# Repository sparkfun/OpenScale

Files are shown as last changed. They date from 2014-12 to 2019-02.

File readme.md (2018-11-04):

SparkFun OpenScale
===========================================================

SparkFun OpenScale (https://www.sparkfun.com/products/13261)

[*SparkFun OpenScale (SEN-13261)*](https://www.sparkfun.com/products/13261)

The SparkFun OpenScale is a simple-to-use, open source solution for measuring weight and temperature. It has the ability to read multiple types of load cells and offers a simple-to-use serial menu to configure calibration value, sample rate, time stamp and units of precision.

Simply attach a four-wire or five-wire load cell of any capacity, plug the OpenScale into a USB port, open a terminal window at 9,600bps, and you’ll immediately see mass readings. The SparkFun OpenScale will enable you to turn a load cell or four load sensors in a Wheatstone bridge configuration into the DIY weigh scale for your application.

The OpenScale was designed for projects and applications where the load was static (like the beehive in front of SparkFun HQ) or where constant readings are needed without user intervention (for example, on a conveyor belt system). A load cell with an equipped OpenScale can remain in place for months without needing user interaction!

On board the SparkFun OpenScale is the ATmega328P microcontroller, for addressing your communications needs and transferring your data to a serial terminal or to a data logger such as the OpenLog, an FT231 with mini USB, for USB to serial connection; the HX711, a 24-bit ADC for weigh scales; and the TMP102, for recording the ambient temperature of your system. The OpenScale communicates at a TTL level of 9,600bps 8-N-1 by default and possesses a baud rate configurable from 1,200bps to 1,000,000bps.

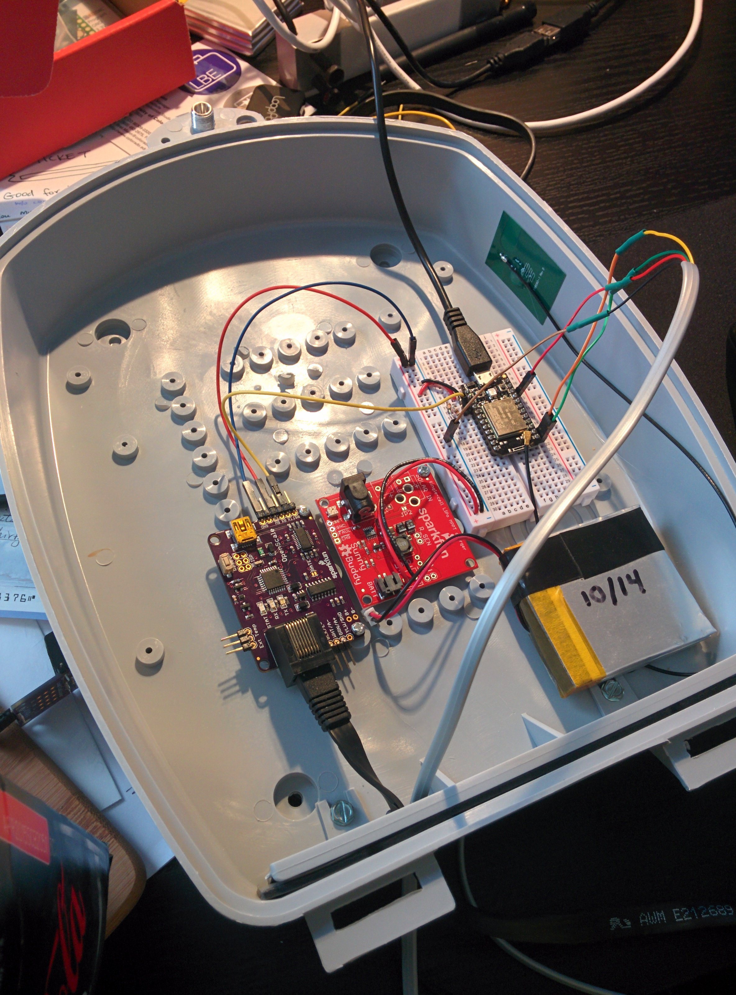
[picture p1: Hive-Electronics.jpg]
The electronics monitoring the bee hive


You can read more about the beehive project that OpenScale is used in the [Internet of Bees](http://makezine.com/projects/bees-sensors-monitor-hive-health/) article.

Repository Contents
-------------------

* **/Documentation** - Images used in the hookup guide
* **/Production** - PCB panelized for production
* **/firmware** - Arduino sketch that runs on the ATmega328P
* **/hardware** - Eagle files

Documentation
--------------

* **[Installing an Arduino Library Guide](https://learn.sparkfun.com/tutorials/installing-an-arduino-library)** - Basic information on how to install an Arduino library.
* **[Hookup Guide](https://learn.sparkfun.com/tutorials/openscale-applications-and-hookup-guide)** - Basic hookup guide for the SparkFun OpenScale

License Information
-------------------

This product is _**open source**_! 

Various bits of the code have different licenses applied. Anything SparkFun wrote is beerware; if you see me (or any other SparkFun employee) at the local, and you've found our code helpful, please buy us a round!

Please use, reuse, and modify these files as you see fit. Please maintain attribution to SparkFun Electronics and release anything derivative under the same license.

Distributed as-is; no warranty is given.

- Your friends at SparkFun.

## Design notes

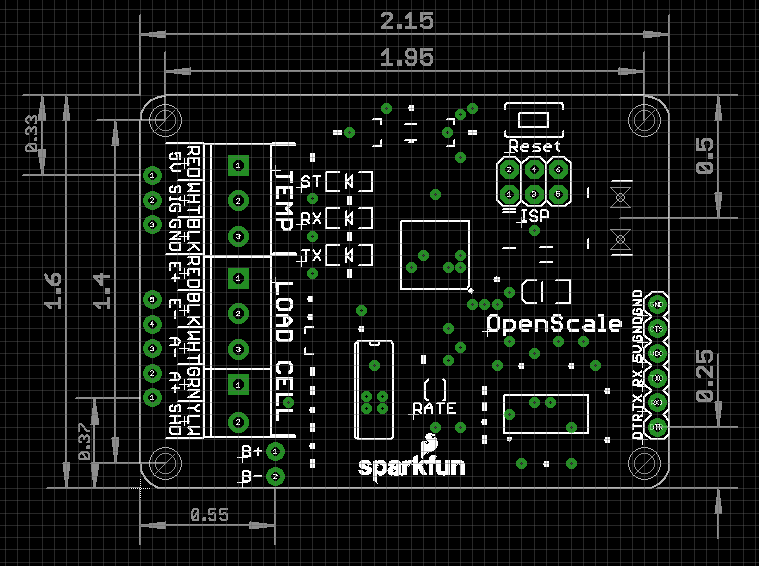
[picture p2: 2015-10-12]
OpenScale Board Dimensions.png

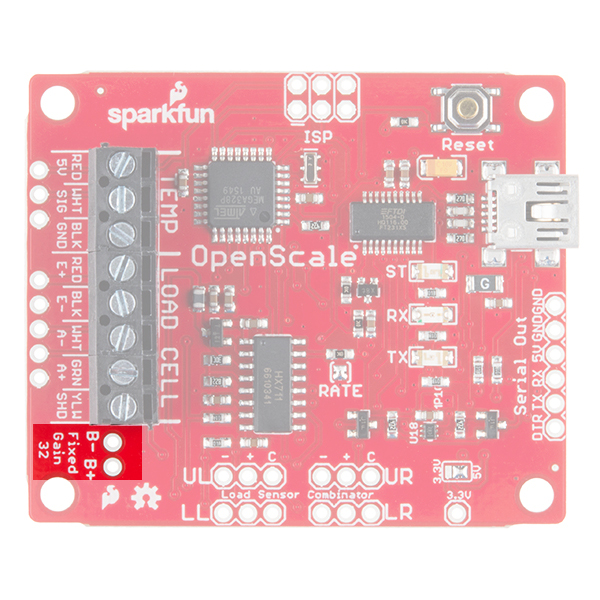
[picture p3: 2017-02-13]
Documentation/OpenScale_gain.jpg

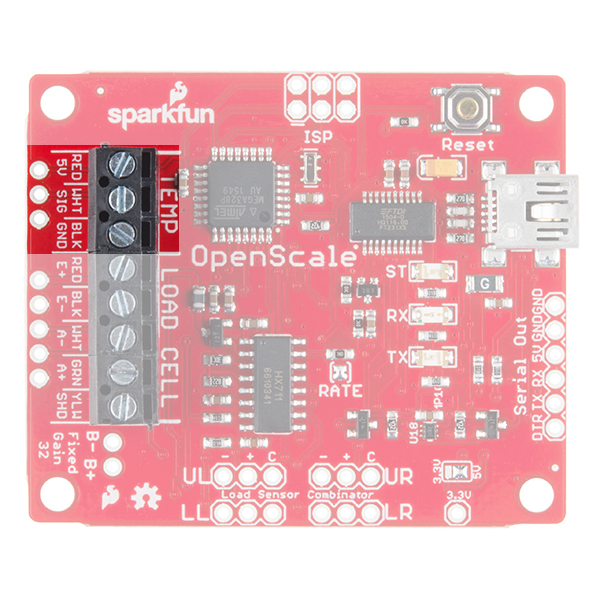
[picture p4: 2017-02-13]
Documentation/OpenScale_TEMP.jpg

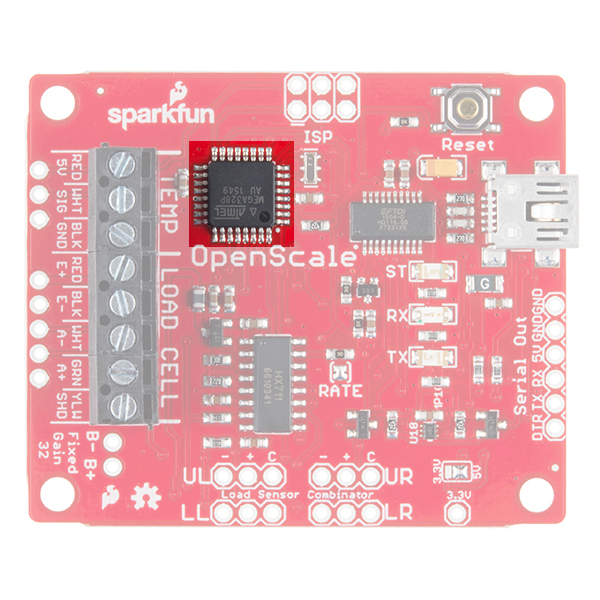
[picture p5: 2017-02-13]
Documentation/OpenScale_atmega.jpg

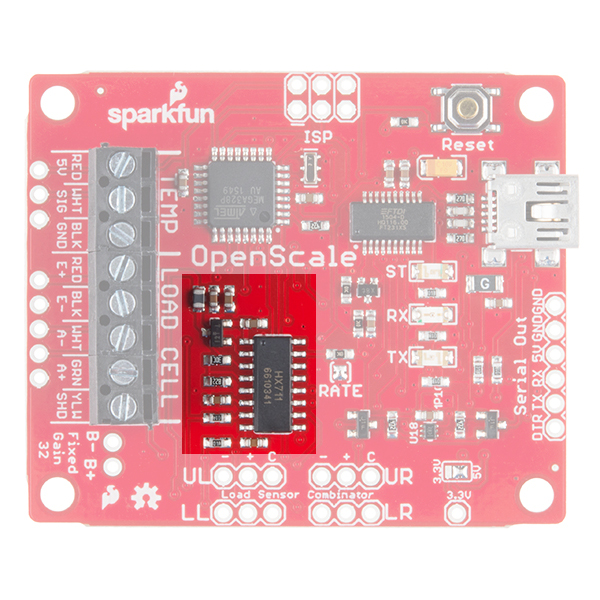
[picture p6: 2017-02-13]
Documentation/OpenScale_HX711.jpg

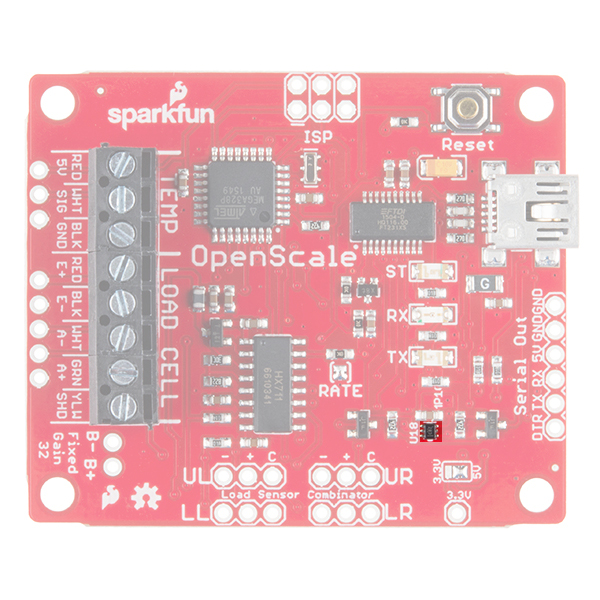
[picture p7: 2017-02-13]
Documentation/OpenScale_Temptiny.jpg

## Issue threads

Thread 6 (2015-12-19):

Commercial product?

zoltan-fedor, 2015-12-19:
Hi,
I know that the readme says that this project is in prototyping phase, but is it expected at any time that this board becomes commercially available, for example via Sparkfun?

Thanks

ToniCorinne, 2015-12-21:
I believe @nseidle is still planning on taking the prototypes and putting them through to Production, but I'm not 100% sure on that timeline.

zoltan-fedor, 2015-12-22:
Thanks @ToniCorinne !

@nseidle , are you still planning on taking this prototype through production? If yes, do you happen to have any timelines?
Thanks

nseidle, 2015-12-22:
Yep! We have protos but there's many steps left. I'm not sure of the timeline but I will guestimate 3-4 months.

@zoltan-fedor - Your interest level helps move the project along. Would you buy the board if it was available? What are you planning on using it for?

zoltan-fedor, 2015-12-22:
Yes, depending on the price I would buy at least one (potentially many more - I might have additional projects around the same topic). My current interest is rebuilding a bee hive scale with OpenScale board. Last year I did it by building a board myself, but would be easier to use a pre-built board.

ToniCorinne, 2016-03-07:
We are working on getting this on the storefront! Closing out the issue, but keep an eye out for the product on the Friday New Product Post.

jgpender, 2016-04-28:
Can I ask about the status of the OpenScale load sensor board? I am also working on a beehive scale that uploads data to phant, hopefully powered for 2-3 months with a couple AA batteries (C cells are plan B). I've bought all the components from Sparkfun - four SEN-10245 load cells, load sensor combinator BOB-13281, HX711 load cell amp, ESP8266 Dev Thing, and a 3.3 step up breakout NCP1402 to keep the supply voltage very constant. Everything works but I am getting huge temperature drift. A temperature change of a few degrees produces a change in the weight reading equivalent to about 10-20 pounds. Realistic temperature swing of 30 degrees are a nightmare. I added a one-wire temperature sensor to the 8266 in the hopes that I could compensate for the drift in software but I can't get the noise level down to the +/- 1 pound I'd hoped for. Does anyone know if the OpenScale breakout will help with the temperature problem? I don't need to deploy my scale until about June so I still have time to work on this before it's too late for this season. Thanks very much, John.

zoltan-fedor, 2016-04-28:
I have just finished building mine, but I didn't use the OpenScale board, but built mine.
I believe the big difference that I did not build the scale, but using one already built : http://www.amazon.com/TREE-Measurements-Large-Shipping-Scale/dp/B008M8FND6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
Expensive, but reliable, no creep. Left some wait on it for 3 weeks and there wasn't even a 0.1 lb creep.

Also I am using a Particle Electron, so it communicates via the 2G network. Plus it has two batteries, a Lipo and a normal USB battery bank and it charges itself from the UBS battery bank whenever needed, so you can swap the battery bank out whenever you want.

jgpender, 2016-04-28:
Hiya Zoltan-

How does that work? Do you strip off the display and then tap into the weight reading somehow? I’m assuming this scale works so well either because it uses better load sensors than the Sparkfun set or because it’s somehow built in the temperature compensation. What sort of temperature swing do you get?

Part of what motivated my project was keeping the cost low. I have friends around here with 50-60 hives so $80 just for the scale would break the budget into a million pieces.

Thanks very much,
John

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

zoltan-fedor, 2016-04-28:
Hi John,
Yes, this is my second generation bee-scale, last year I built one too - that was with a low-end scale and I had all kind of problems with the reliability of the scale (although no major temperature swings). Currently I am not seeing any temperature swings and this is a high-end scale, so I would be surprised to see any.
Yes, I just stripped off the display and connected the HX711 load cell amp and did the calibration and that's it. I was testing the whole setup in the last 2 weeks - working pretty well.
I really like the Electron, although I must say there were quite a few gotchas when I had to bug the guys at Particle to find solutions to problems of the Electron, specially around sleep modes, low power stages, keeping 2G connection alive, etc.

Zoltan

ps.: Yes, $80 is pretty expensive, but me being a beekeper myself - I would never put a scale under each hive, no point in that, at least not for what I use it. I usually put a scale under a single hive or maybe two - as it is used as an indicator of nectar flow, not the health of the individual hive, so that way it worth the investment for a whole yard.
But yes, for generation 3 of my scale, I will probably do some research to find a cheaper version of the scale - one which is still good enough (no creep, no temperature swings, measures up to 200lb, etc), but cheaper

jgpender, 2016-04-28:
Hi Zoltan-

I only have the one hive so the expense of the scale is not a big deal, especially when compared to all the aggravation I’ve had. I tried using the Particle Photon but it froze up a couple times so I thought I’d try the ESP8266 board, partly because of the lower price. Talk about “gotchas.” What a pain that board was. I went ahead and used GND, pin 5, pin 0, and pin 4 to connect to the load cell amp and wasted all kinds of time trying to figure out why it didn’t work. Finally realized you’re supposed to connect pin 0 to ground when you want to reset the bootloader so pin 0 doesn’t sleep when you sleep the board.

Shot myself in the foot a second time when I hooked the one-wire temperature sensor to pins 12 and 16. Sleep mode requires a jumper on the blue oval below and I forgot that XPD was the same as pin 16 so, again, the board wouldn’t sleep.

Personally, I’m most comfortable with the Arduino Yun board because I’ve been using command line Unix for 35 years. Scripting, scp, blah blah blah like falling off a log. Spendy board, though, and no sleep mode.

None of my friends would put a scale under every hive either. Usually they set up maybe a half dozen in some field, then another batch in some other location, etc., so they’d only want a scale under one hive per set. Even so, I heard a lot of whining last fall when we talked about the price, even in the $30 range. It was smart of you to start with an industrial-grade solution then work down to something cheap. Starting cheap has cost me all kinds of time.

John

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

zoltan-fedor, 2016-04-28:
Hi John,
I am doing a lot of linux too for a few years now, so last year I actually built the whole thing on a Raspberry, but I had a challenge managing its power needs, so now I went for the Particle Electron. I am operating it in the middle of the woods (literally, we take the hives to a black lotus forest), where there is no power source, wifi or anything else (but the woods). :-)

For now I am pretty happy with the Particle Electron. I can run it for about 4-5 days from the included 2000mAh battery making a measurement and sending it to my server in every 15 mins and I can add an any-size external USB power bank and it charges itself from it when the 2000mAh runs low (using a relay switching the USB cabel, because power banks turn themselves off after low power use - when the 2000mAh is full).
I can get a 10000mAh USB power bank fairly cheap ($10), so with that the setup can run for about 24 days in total.
Going any higher would require adding a solar panel (which I did for some other projects) or decreasing measuring frequency to save power.

All-in-all, I am happy with the choice of going industrial-grade with the scale for now and then working down when (if) I plan to produce multiple of these scales.
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
ADataDate, 2016-04-29:
You might also want to look into noise that might be on your lines. Another
cool thing about openscale is that Nate added an inductor on the digital
input so some of that noise is immediately filtered. The Inoor weight
actually looks pretty good compared to the outdoor but I can see why would
be frustrated if you are trying to the readings into +/- 1% tolerance.

I would order new load cells. The problem with buying a scale is that you
will get load sensors instead of cells and you would have to configure them
into a whetstone bridge to get it working properly. Do you know the max
weight of what you are trying weigh? We have this Load Cell (data sheet
below as well). It has a pretty good temperature range, creep is +/-0.03%
every 3 minutes.
https://www.sparkfun.com/products/13329
https://cdn.sparkfun.com/datasheets/Sensors/ForceFlex/TAL220M4M5Update.pdf

There are certainly better load cells out there for different applications.
I would check out Honeywell, I usually stop there first for more robust
mechanical projects.

To start compensating the system I would look at one varying factor at a
time. This is how I would get my comp coefficients:
For Creep:
Take a known weight and put in on the scale for as long as the data sheet
says before it needs to tare (in the load cell above its every 3 minutes).
Measure the difference in the measured weight against the known weight. Do
this several times and increase the amount of time with each test.
Eventually you should get a curve which you could probably linearize if you
wanted to keep things a little more simple. The slope of the linear curve
would be your creep coefficient. Yo'll probably need to update this value
often as the creep will change with time.

For Temp:
Do basically the same thing in as much of a controlled environment as you
can. Get ambient readings first then take it outside to get the crazy
stuff. when taking it outside try to shield your setup from as much other
environmental forces as possible. It would be great to characterize the
curve based on you controlling the temperature & humidity/pressure, Since
that isn't totally possible this curve fitting may take some time. Once I
have a coefficient I can test I would set a known weight on the scale in
known temps with an idea of the error might be and adjust the coefficient
statically. You may need to update this value often.

For environmental factors:
Can you dig posts down into the ground, basically create a foundation for
your setup? then it is more likely your setup will not be as susceptible to
vibration. Can you create a housing around the electronics and the
object(s) you are weighing? This will help with wind forces. Though it
would be interesting to see a map of readings with weather data laid over
to see possible correlations. I'd use nice and thick cables, plenty of
electrical tape. Moisture is bad news for transmission.

I'd like to see your data again when you have it set up with OpenScale and
new load cells.

Send me an email at mary.west@sparkfun.com and I'll get you a prototype
loaded the the first sketch ready to go by this afternoon.

Thanks for sharing your progress!

On Thu, Apr 28, 2016 at 4:58 PM, John Pender <notifications@github.com>
wrote:

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

abohnsac, 2016-09-06:
I'm new to all of this but wondering if anyone has any new information on using the openscale board with their hive sensors. It seems like this should make it more simple and that this has progressed since the release of the board. I'm planning on using it with the raspberry pi 3 to broadcast data. Any guidance or advice is appreciated.

Closed 2016-03-07.

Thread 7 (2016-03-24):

v04 Checklist issues

ericorosel, 2016-03-24:
1) May want to add your name to the Engineer field, currently it's just Nate's (not sure who's board it is)

2) SCH and BRD both show v03, I think it should say v04

3) There is a 470pF CAP on the BOM (CAP-07884) that I couldn't find in the design

4) Need to run the DRC with a vetted DRC from GitHub in the Sparkfun_eagle_settings repo (currently set to Sparkfun_2-Layer which is old)

5) 27 ohm resistors do not have silk in the package

6) looks like the inductor needs a prod id in the attributes

I think that's it!

ericorosel, 2016-03-24:
Just realized I did a check on the wrong design, my bad.

Closed 2016-03-24.

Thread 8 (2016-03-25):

Actual v04 Checklist Review

ericorosel, 2016-03-25:
1) some nets are not drawn straight out one grid space from the pin: J2, R12, R11

2) got some over sized nets around the FT chip (> 0.006")

3) I would like to see a jumper diagram for the 3-way jumper, otherwise I think the description needs some cleaning up

4) BOM:
- 470pf on BOM not in design
- 4 x 10K in design but only 2 on BOM
- Push Button in design and on BOM are different
- TRANS-11151 not on BOM

5) board dimension thickness is 0.1" instead of 0.08"

6) there are both 0.02" vias and 0.015" vias in the design (didn't look intentional)

7) C4 has an unnecessary bridge to GND (just looks kind of funny)

8) the trace-nubs at the end of the pads on the USB look like they were intentionally placed there, is this for AOI inspection?

9) This is knit-picky, but there are a few traces that either enter a pad at an angle or do not enter the pad at the pad's center point. Some of the mentioned instances are in tightly spaced areas, but some are not. Might be worth trying to clean up some of the instances that have some extra space around them. (optional)

10) TMP102 does not appear to have tNAME or tVALUE elements in the BRD

11) Looks like the bottom-side labels for JP1 (the 3 x 1 Temp header) are no longer lined up with the through-holes

12) Not sure if the upper two standoffs were intentionally placed out from the corner of the board, but I thought it worth mentioning if this was unintentional.

ADataDate, 2016-03-29:
Board and Schematic files updated.

ericorosel, 2016-03-29:
Issues all resolved, closing!

Closed 2016-03-29.

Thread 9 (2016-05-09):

Engineering Review

ToniCorinne, 2016-05-09:
- Move "All units in inches" note to Measures layer
- scoot passives out from USB connector(20 mils) for AOI
- bump miter out 1 0.5 grid space
- move mounting hole on grid
- Update schematic text to vector

- Following on hold until verifying with Nate:
- Change silk to  "FTDI Out" / "Serial Out"
- Update FTDI silk to RXI, TXO

ToniCorinne, 2016-07-15:
Closing this out

Closed 2016-07-15.

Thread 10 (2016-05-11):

Engineering checklist issues:

ericorosel, 2016-05-11:
(1) The design version number is still v04 - This should be v10 if we go to REDS or v05 id we do another proto round. Ether way, the version number needs to change in order to reflect changes from v04.

(2) Need an extra CAP-00810 in the BOM. Currently the design has 9 0.1uf caps and the BOM only reflects 8 of the 9.

(3) I think if the "Serial Ou"t header is to be used as a general serial out, then we should adjust the header so that another micro (pro mini, oplelog, etc.) could be connected directly to the OpenScale with female and male headers without the use of jumper wires. Right now the header is set to mate with an FTDI, which is all good, but it seems redundant given the board has an on-board FTDI chip and a USB connector. I think it would be more intuitive to order the pins similarly to the FTDI's for easy connection to another micro based device. If I am completely off base as to the function of this header please disregard the above.

(4) I know that C14 is directly in the way of the "Serial Out" label being centered, but it would be nice to have that label centered on the header. Maybe smaller font could make this doable. If the font size is already at it's minimum for the need of the design then disregard.

(5) Looks like the trace connecting to the TMP on pin 3 is entering the pad at an angle. It would be nice to have that trace enter the pad at the toe like the rest.

(6) Top copper polygon gets chopped at the corners of the board. I think it would be nice to mimic the bottom copper polygon in nature (same dimension border).

ericorosel, 2016-05-11:
Mary just reminded me that the Openlog has the same serial header arrangement as the FTDI, which makes point (3) not an issue at all. Please disregard point (3), and my apologies for the confusion.

ADataDate, 2016-05-11:
Hey Eric,

Pushing changes now. Sorry if this has been frustrating for you. Glad I
have my revision quota done for the year.

(1) The design version number is still v04 - This should be v10 if we go to
REDS or v05 id we do another proto round. Ether way, the version number
needs to change in order to reflect changes from v04. - Changed to v10. The
only changes are adding a cap, connecting the FET to 3.3V which is how it
should be (and when i cut traces and added jumper to exposed trace it
worked perfectly), rounded corners, silk. I don't see how these changes
would affect the performance or intended use of this product. I'd rather
get a product out. However, if you feel it should go for another round of
protos I will take that into consideration as you have more experience with
these types of things here at Sparkfun.

(2) Need an extra CAP-00810 in the BOM. Currently the design has 9 0.1uf
caps and the BOM only reflects 8 of the 9. - Added part in Sparkle

(3) I think if the "Serial Ou"t header is to be used as a general serial
out, then we should adjust the header so that another micro (pro mini,
oplelog, etc.) could be connected directly to the OpenScale with female and
male headers without the use of jumper wires. Right now the header is set
to mate with an FTDI, which is all good, but it seems redundant given the
board has an on-board FTDI chip and a USB connector. I think it would be
more intuitive to order the pins similarly to the FTDI's for easy
connection to another micro based device. If I am completely off base as to
the function of this header please disregard the above. - Discussed, we
agree to keep it the way it is

(4) I know that C14 is directly in the way of the "Serial Out" label being
centered, but it would be nice to have that label centered on the header.
Maybe smaller font could make this doable. If the font size is already at
it's minimum for the need of the design then disregard. - Changed size &
Centered.

(5) Looks like the trace connecting to the TMP on pin 3 is entering the pad
at an angle. It would be nice to have that trace enter the pad at the toe
like the rest. - Done, good catch

(6) Top copper polygon gets chopped at the corners of the board. I think it
would be nice to mimic the bottom copper polygon in nature (same dimension
border). - Done

Mary

On Wed, May 11, 2016 at 2:05 PM, ericorosel <notifications@github.com>
wrote:

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

ADataDate, 2016-05-11:
https://github.com/sparkfun/OpenScale/tree/v04

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

Closed 2016-05-11.

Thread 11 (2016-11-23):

Screw Terminals in .brd/.sch Files

elizabethsrobert, 2016-11-23:
Hello OpenScale!

The Assembly BOM and storefront pictures show two 3-Screw Terminals and one 2-Screw Terminal being used to populate the board. The .Brd/.Sch Files do not reflect this production change. To complete the 3D model image properly, I just need the number/type of screw terminals changed to reflect this as well as their values. Currently, files have one 3-Screw Terminal and one 5-Screw Terminal.

Thank you!

elizabethsrobert, 2016-12-02:
Used original intended parts to complete 3D design model.

Closed 2016-12-02.

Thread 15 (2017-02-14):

[Feature Request] Consistent weight measurements across a range of temperatures

kevinjos, 2017-02-14:
I notice in a days sample of recordings that weight is a function of temperature W(t). Has anyone taken a look at modeling this relationship such that the OpenScale can be configured to output consistent weight measurements across a range of temperatures (0 - 40C)? What is the major contributing factor? Is it the temperature drift of the [ADC](http://image.dfrobot.com/image/data/SEN0160/hx711_english.pdf)? Or a property of the materials used in the strain gauge? If it's the former it might be worth correcting in the OpenScale firmware. The latter may require scale-specific calibrations.

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

ADataDate, 2017-02-14:
In the photos above are you weighing something constant? A 10 degree change in 2 minutes is definitely going to place mechanical stress on the load cell to cause problems.  A one pound change over 10 minutes does seem excessive though.

This is actually common and expensive problem for a couple of reasons. The HX711 load cell amplifier has an input offset of +/- 6nV/C. This offset can drift further with temperature. Another reason is load hysteresis, which is a mechanical property of the load cell itself. Since each load cell has it's own range for the drift- if you are using 4 strain gauges the readings could be much more off. Keeping the temperature stable in your system is the best way to deal with this but it will still drift some. But will be mostly creep if you can get your system to be more temp independent.  creep causes issues with the hysteresis as well. Creep fatigue happens within the first few moments of a weight reading, then there's a "bounce back" or creep recovery effect as the gauge gets used to deformation.

 NIST actually did a study on creep and found there is a great variety in the magnitude, direction and complexity of the creep between 11 identical strain gauges.  To compensate for this I'd recommend placing a known weight on the scale for 10 minutes or so and calculate the change in weight with time. This test will work best if the temperature is stable. Most creep will occur in the first few moments and should taper off. I'd repeat this test with several weights since you can't assume the creep in constant between different sets of known weights.

https://www.nist.gov/sites/default/files/documents/calibrations/vdi-312.pdf

We haven't performed the test you spoke of but that's because it's a known problem and is load cell dependent. I have heard that 6-wire beam style load cells work best but that also assumes you know what your max weight will be so you load cell limit is only slightly above your maximum. This way you don't waste any range on the ADC.

ADataDate, 2017-02-14:
Also how stable is your power supply? have you tried measuring the excitation voltage (E+/E-)? Any variation in voltage here goes through an amplifier which can cause offset issues as well.

kevinjos, 2017-02-15:
Thank you for the feedback @ADataDate. The weight is a constant 20lbs. The 10 degree C change happens over ~1h. I do not think that I am observing creep. The same  weight has been on the scale, in constant operation, for 24 hours and counting.

I am using the same 4-strain gauge, 400lbs max, postal scale from the Internet of Bees write up. I agree that one issue may be that I am not in the full range of the ADC. I am powering the scale from a Beaglebone Black, this may also be an issue.

I will try adding more weight and introducing an external power supply. I will also run the ADC temperature drift calculation to see what the expected change is based on the +/- 6nV/C spec.

nseidle, 2018-11-06:
Hi @kevinjos - This issue is getting pretty old so I'm going to close it. If you have any news to report, please feel free to re-open.

I don't plan to add temperature compensation on-board to OpenScale. Rather, we exposed the onboard temp and an option external temp sensor so that users could post-process their readings depending on their load-cell drift due to temperature.

Closed 2018-11-06.

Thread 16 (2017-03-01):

Getting "inf" for weight

felixgalindo, 2017-03-01:
Serial Load Cell Converter version 1.0
By SparkFun Electronics
No remote sensor found
Minimum time between reports: 868
Press x to bring up settings
Readings:
1982,inf,lbs,164148,24.31,0,
2850,inf,lbs,164096,24.31,0,
3877,inf,lbs,164174,24.31,0,
5364,inf,lbs,164185,24.31,0,
6850,inf,lbs,164152,24.37,0,
8337,inf,lbs,164218,24.37,0,

ADataDate, 2017-05-03:
Have you been through the calibration menu yet? If yes, then We'd need to troubleshoot your connections and look at hardware. If no, then enter "x" in the com port to bring up the calibration menu and then enter 1 to tare to zero and then enter 2 to calibrate it.

nseidle, 2018-11-06:
Closed from inactivity. Please re-open if you still have the issue.

Closed 2018-11-06.

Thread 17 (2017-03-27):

Temp and Humidity

dapug, 2017-03-27:
Your Make article mentions the HTU21D, but in the schematic here I only see a place to hook up a DS18B20.  Can you explain?

ADataDate, 2017-03-27:
Openscale does not use the HTU21D. It relies on an on-board temperature sensor (TMP-102) as well as the external, waterproof DS18B20 temp sensor. The Make article came out before the Openscale design was finished and used different sensors.

dapug, 2017-03-27:
Thanks, this is what I suspected.  So basically, measuring humidity is a non-goal for the project.  Just wanted to confirm.  I can see value either way.

Closed 2017-03-27.

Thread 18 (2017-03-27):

Adding Wifi

dapug, 2017-03-27:
It looks like all communication is serial, so I assume if you want it connected on wifi (via ESP-x of choice) then that would be done with a serial connection to pipe the data to an ESP8266/32 device, and the ESP then relays that to a server destination of choice (via REST or HTTP or MQTT or whatever).

Since ESP-01/12/32 is not built into OpenScale, shouldn't there be a simple UART connection for it externally, and/or a way to bypass the built in FT231?  Or am I way off in the weeds here with a non-scenario for OpenScale?

ADataDate, 2017-05-03:
Openscale has a UART connection (next to the USB labeled "Serial Out") specifically for connecting external serial devices (like OpenLog). Is that what you were asking?

nseidle, 2018-11-06:
Closed due to lack of activity. Please reopen if you have any questions. ADataDate is spot on. You can add wifi pretty easily through the UART connection.

Closed 2018-11-06.

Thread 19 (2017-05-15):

How to get scale readings (preferably in Python)?

kramer65, 2017-05-15:
I've got a load cell hooked up to my openscale which in turn is connected to my Raspberry Pi, and I'm trying to get some readings. After ssh'ing into my raspi I load up the openscale menu like this:

    screen /dev/ttyUSB0 9600

I got to the menu, followed the instructions to tar to zero and calibrate it. But from here I'm kinda lost in getting results. I can go into calibration mode again and see results, but how do I get readings outside the calibration menu? And more importantly; how do I get results into Python?

Can anybody give me some hints in the right direction?

kramer65, 2017-05-25:
In the end I used pyserial to get the readings like this:

import serial
with serial.Serial('/dev/ttyUSB0', timeout=1) as ser:
    while True:
        line = ser.readline()
        print line

Closed 2017-05-25.

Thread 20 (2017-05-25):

Readings wrong from third reading. And _always_ from third one.

kramer65, 2017-05-25:
I'm having massive trouble with my OpenScale. I've tarred it to zero and calibrated it with a one kilogram weight. After that I exit the calibration program and exit the menu to get the readings. In the meantime I do not remove the one kilogram weight. After exiting the menu, the first two readings are correct, but the third one is wrong (see the readings below this message). The weird thing is that it's always the third reading. I've repeated it about 20 times, and it's without exception, _always_ the third one.

When I go back into calibration after this (and I don't touch the weight), it again reports 1 kg in the calibration again. In summary, it always works well in the calibration program, but after exiting, the values are wrong starting from the third value.

Does anybody know what could be wrong here?

```
Reading: [1.0174 kg]   Calibration Factor: -11746
Reading: [1.0158 kg]   Calibration Factor: -11746
Reading: [1.0172 kg]   Calibration Factor: -11746
Reading: [1.0151 kg]   Calibration Factor: -11746

Serial Load Cell Converter version 1.0
By SparkFun Electronics
No remote sensor found
System Configuration
1) Tare scale to zero [-23519]
2) Calibrate scale [-11746]
3) Timestamp [On]
4) Set report rate [711]
5) Set baud rate [9600 bps]
6) Change units of measure [kg]
7) Decimals [2]
8) Average amount [4]
9) Local temp [Off]
r) Remote temp [Off]
s) Status LED [Blink]
t) Serial trigger [Off]
q) Raw reading [On]
c) Trigger character: [48]
x) Exit
>Exiting
152222,1.02,kg,-32345,   # the first two are correct
152933,1.02,kg,-32334,
153916,0.06,kg,-32331,   # from here it's wrong
155351,0.04,kg,-32317,
156785,0.03,kg,-32300,
158220,0.04,kg,-32323,
159654,0.04,kg,-32311,
161088,0.04,kg,-32327,
162523,0.04,kg,-32368,
```

kramer65, 2017-06-01:
Ok, after messing with the settings I now have it working. No idea why though, since I set everything back to how it was in in the settings I posted above.

So my only advice to anyone reading this: mess with the settings.. :S

nayanagg, 2018-11-03:
Hi, @kramer65 I'm facing the exact issue which you have mentioned above. Kindly let me know how to correct this mess.  Early reply is much appreciated!
Cheers!!

Closed 2017-06-01.

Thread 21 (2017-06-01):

OpenScale doesn't remember zero point after powering down and up again

kramer65, 2017-06-01:
I've got the OpenScale attached to my Raspi, which after some [initial](https://github.com/sparkfun/OpenScale/issues/19) [trouble](https://github.com/sparkfun/OpenScale/issues/20) now works fine. The only problem I now still have is that it doesn't remember the zero point between reboots of the Raspberry Pi. The calibration is stored correctly between power downs (`-9649`), but the zero point (now `-23859`) is constantly forgotten and reset to `8647409`.

For this reason I need to tar to zero after every reboot which is absolutely annoying.

Does anybody know why it doesn't remember the zero point and how I can solve this? Another solution would be if I could set the zero point using Python so that I can simply set it in the beginning of the script which reads out the measurements.

All tips are welcome!

ADataDate, 2017-06-01:
Yes - There is an updated version of the firmware here: https://github.com/sparkfun/OpenScale/blob/master/firmware/OpenScale/OpenScale/OpenScale.ino which solves that problem.

Sorry Openscale has put you through such a crucible. I did look into your-every third weight-problem but I wasn't able to reproduce it. If you have any more questions open another issue - I'm watching this a little more closely now.

kramer65, 2017-06-02:
Hi @ADataDate - Thanks for the response and the suggestion. Good to hear there are things moving with the OpenScale. I'm kinda lost with that link though. Any idea how I can load that firmware onto the OpenScale board from a raspi?

asachs01, 2018-05-13:
@kramer65 @ADataDate +1 to this. I've not been able to find a method for flashing the updated firmware to the openscale.

nseidle, 2018-11-06:
Hi @kramer65 @asachs01 @nayanagg - This is a bit old but to answer the original question: The INO file is an Arduino sketch that can be compiled and uploaded to OpenLog via the Arduino IDE (no other tools required). [Here's](https://learn.sparkfun.com/tutorials/installing-arduino-ide/all) a tutorial to get you started.

You can download the entire repo [here](https://github.com/sparkfun/OpenScale/archive/master.zip). The INO that you will need to open in Arduino is in the firmware/OpenScale directory.

I've fixed a handle of large and small bugs in v1.2. If you get the chance, please try out the new firmware. I welcome your feedback.

nseidle, 2018-11-06:
There's additional info about upgrading the firmware [here](https://learn.sparkfun.com/tutorials/openscale-applications-and-hookup-guide?#upgrading-the-firmware).

Closed 2018-11-06.

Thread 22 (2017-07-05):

System config menu appears multiple times

Thurgs, 2017-07-05:
Sorry, I am quite new to this (and loving it so far).
I have been using the OpenScale from Sparkfun and also some Arduino Pro Minis, but the new ones seem to have something strange happening where if I enter multiple characters at one time (such as 'x1x') it just prints the menu 3 times in a row. It appears to just read the first character and just use this in the place of each of the characters. If I print 'xxxx' it will just open the menu 4 times.
In the OpenScale and the older Pro Minis, I could send 'x1x' all at once and it will enter the menu, Tare the scale and then exit the menu. This is what I would like to do for my application.

I have reloaded the code and put it onto the old and new devices and it seems that the new Pro Minis are always having this issue where the older ones and the OpenScale device do not.

Would really appreciate any help and guidance.

nseidle, 2018-11-06:
Yup. This was really annoying. Sorry it took so long to fix but it's good to go in v1.2. I've fixed a handful of large and small bugs in v1.2. If you get the chance, please try out the new firmware. I welcome your feedback.

Closed 2018-11-06.

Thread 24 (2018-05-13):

Updating Firmware

asachs01, 2018-05-13:
Howdy :wave: ! I was curious if there was a clear guide on how to update the firmware on the openscale board. I've not been able to find the info on the Sparkfun site, though someone does appear to have done this (see the comments on the board product page).

asachs01, 2018-05-13:
Ah! NVM. Should have read the instructions in the firmware:
```
OpenScale ships with an Arduino/Optiboot 115200bps serial bootloader running at 16MHz so you can load new firmware
 with a simple serial connection. Select 'Arduino Uno' under the boards menu to reprogram the board.
```

Closed 2018-05-13.

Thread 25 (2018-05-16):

Using Ruby 'rubyserial' or 'serialport' gems to read data

asachs01, 2018-05-16:
Has anyone used either of these gems to successfully read data from the board? I can get the data via the serial connection by itself, but can't seem to get either of the gems, or pyserial for that matter, to read the data produced by the board.

nseidle, 2018-11-06:
@asachs01 - Any luck? We're not really ruby folks. Let us know if you were able to hook in to the serial stream. It would be helpful to know for other users.

asachs01, 2018-11-07:
@nseidle I did make some progress over the past couple months. What I have now that's _sort of_ working is this:

```
  def initialize
    sp = Serial.new config[:port]
    sp.write("config[:writechar]")
    weight = sp.read(config[:readbytes]).split(',')
    if weight.nil?
      do weight
    else

    end
  end
```
It's not complete (this is part of a side project outside of $dayjob), but it gets close to working.

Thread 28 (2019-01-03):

Updating firmware

WyattLiu, 2019-01-03:
I have tried to update following the instruction here https://learn.sparkfun.com/tutorials/openscale-applications-and-hookup-guide/all#upgrading-the-firmware

But I am stuck at missing a header file, may I ask what was the assumption that we have to install before hand?

Arduino: 1.8.8 (Linux), Board: "Arduino/Genuino Uno"

OpenScale:64:59: error: OneWire.h: No such file or directory
compilation terminated.
exit status 1
OneWire.h: No such file or directory

This report would have more information with
"Show verbose output during compilation"
option enabled in File -> Preferences.

nseidle, 2019-01-03:
Sorry. I should have made that more obvious, but you got it figured out.

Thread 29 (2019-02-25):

cannot load new firmware

MIKMAI, 2019-02-25:
I tried to load firmware according to instructions on openscale page but all i get is "no matching function for HX711" (i think i got the libraries right)
 I followed instructions described on openscale page but still don't manage to get it work.
I'm not familiar with coding so much that i could find the problem from the code right away.
Just need openscale for hobby project.

nseidle, 2019-02-26:
Please post the errors from the Arduino IDE if possible. "No matching function for HX711" sounds like a library issue. Be sure to grab the latest from https://github.com/bogde/HX711

MIKMAI, 2019-02-26:
Yes it is probably some error with the library. I used links on openscale instructions page. Thanks I'll try that link also.

The error message is:
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

Instructions page:
https://learn.sparkfun.com/tutorials/openscale-applications-and-hookup-guide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

nseidle, 2019-02-26:
Fooey. Looks like @bogde may have changed how the library works and broken existing sketches.

Checkout their new example [here](https://github.com/bogde/HX711/blob/master/examples/HX711_basic_example/HX711_basic_example.ino).

I suspect you will need to change a few lines of OpenScale:

    HX711 scale;

and in setup add:

    scale.begin(DAT, CLK);

I don't have hardware available atm but will update firmware in the coming days.

nseidle, 2019-02-26:
I pushed a new version. Please kick the tires and let me know if you still have issues. The changes I made simply make the code compile, no function changes.

Closed 2019-02-26.

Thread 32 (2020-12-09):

Tare always 8388607 weight nan

dawidwekwejt, 2020-12-09:
First time I connected C to WHITE, + to RED and - to BLACK. With this I got always 0 weight, so I changed wiring: C to RED, + to WHITE and - to BLACK. After that I had tared scale and calibrate it with 1L botle. In calibration mode I set _1.000000000000_. Why no I got _nan_ value?

### Current state

**Wiring**
UL, UR, LL, LR
**C** -> RED
**+** -> WHITE
**-** -> BLACK

**Configuration**
Serial Load Cell Converter version 1.2
By SparkFun Electronics
No remote sensor found
System Configuration
1) Tare scale to zero [8388607]
2) Calibrate scale [0]
3) Timestamp [On]
4) Set report rate [2000]
5) Set baud rate [9600 bps]
6) Change units of measure [kg]
7) Decimals [2]
8) Average amount [4]
9) Local temp [Off]
r) Remote temp [Off]
s) Status LED [Off]
q) Raw reading [On]
t) Serial trigger [On]
c) Trigger character: [48 / '0']
x) Exit

**Log**
1006550,nan,kg,8388607,
1008651,nan,kg,8388607,

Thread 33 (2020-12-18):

Raspberry Pi Implementation

Vanlon, 2020-12-18:
Is there any documentation on this on how to use it on a R Pi?  I can get the serial output, but how do you access the menu.  Possibly some example Python scripts.

circuitmike, 2021-07-01:
I use one of these with a Raspberry Pi. The easiest way I found to do it was to use the [pexpect library](https://pexpect.readthedocs.io/en/stable/). For example, here's a snippet of code where I use pexpect to tare the scale:

```python
    def tare(self):
        logging.debug('tare')
        self.lastTare = int(time.time())

        px = pexpect.fdpexpect.fdspawn(self.serialObject)
        px.expect('\n[-.\d]+,[a-z]+,[-.\d]+')
        px.send('x')
        px.expect('\n>')
        px.send('1')
        px.expect('Tare point 1: [-\d]+')
        px.expect('Tare point 2: [-\d]+')
        px.expect('\n>')
        px.send('x')

        i = px.expect(['\n[-.\d]+,[a-z]+,[-.\d]+', '\n>'])

        if i == 1:
            logging.debug('Stupid bug encountered - sending another x')
            px.send('x')
            px.expect('\n[-.\d]+,[a-z]+,[-.\d]+')
            logging.debug('Extra-x hack appears to have worked')
```
The "extra X hack" at the end there is because I'm using an old version of the OpenScale firmware that has a bug where sometimes hitting "x" at the menu doesn't exit, but just re-displays the menu, and you need to hit "x" again for it to actually exit. I should really update the firmware at some point...

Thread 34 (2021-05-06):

Serious issue with menu interface over Serial Monitor

chasegrif, 2021-05-06:
When using the serial monitor in Arduino IDE and trying to access the menu, the line ending drop-down menu in the serial monitor window (newline, carriage return, or both, next to the baud rate drop-down menu) adversely affects the behavior of the program.

When using "newline", commands/inputs are ignored, such as sending 'x' to access the menu.

When using "carriage return" sometimes the user input is recognized, but the serial monitor stops outputting (basically the program hangs indefinitely)

When using both "NL & CR" the program interprets this as a "double input" as if the enter key was pressed twice, so when accessing a menu option, the second menu receives a blank/null input and returns to the main menu, basically printing the menu twice.

This behavior depends on the option being selected, such as changing the units (which works like boolean logic) versus a menu option that waits for user input (such as the calibration function)

However, I was successfully able to interface with OpenScale menu via PuTTY, which worked flawlessly.

The problem is that I am trying to use this platform for a course I am teaching and want my students to be able to do this on their personal computers and I would like for them to be able to do everything from the Arduino IDE rather than having them download a separate program.

Also, when running this program on an Arduino Uno, does anyone know off-hand which of the digital input pins is assigned for the remote sensor? Is it 4? Where is it defined?  I could find this with some digging but just wanted to ask if anyone knew already.  Will a digital thermocouple work in place of the "remote sensor" in the program? So long as I have it connected to that pin?

Thank you so much for your time, I genuinely appreciate how much work went into this project, it is leaps & bounds beyond the typical HX711 sketches I've used during the past in terms of features and user interface, which I would love to be able to share with my students, I'm just having frustrations with the interface not responding correctly.

Please ask me any questions regarding my issue, I will troubleshoot/test/check anything you think is worth investigating, thanks again.

nseidle, 2021-05-06:
Wow. I wrote this sketch 7 years ago.

I recommend [Tera Terminal](https://learn.sparkfun.com/tutorials/terminal-basics) over using the Arduino IDE's serial monitor.

Sorry, I don't have [whitespace filtering on the input](https://github.com/sparkfun/OpenScale/blob/master/firmware/OpenScale/Menus.ino#L105). Whatever character arrives gets tested, include /n and /r. If you'd like to improve it I welcome a PR.

OneWire sensor is defined [here](https://github.com/sparkfun/OpenScale/blob/master/firmware/OpenScale/OpenScale.ino#L97).

Closed 2021-05-06.

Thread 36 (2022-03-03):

Nothing happens after I enter in a known weight

Erdcgh, 2022-03-03:
When I try to calibrate the scale, it ask me "Please enter the weight currently sitting on the scale" which I then enter in "0.1" for the 100g weight that I placed on it. It then echo back that number but then nothing else happens. Am I missing something

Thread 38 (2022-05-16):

[Info Required]: Need to know the readings

iamdipanshusingh, 2022-05-16:
Hi, I'm trying to read the data in a flutter app, and getting the readings as follows:
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

can someone plz explain the readings to me?
Also having a similar issue like #35, on putting 1.25kg the output weight increases by 2-3kg

@nseidle plz have a look once

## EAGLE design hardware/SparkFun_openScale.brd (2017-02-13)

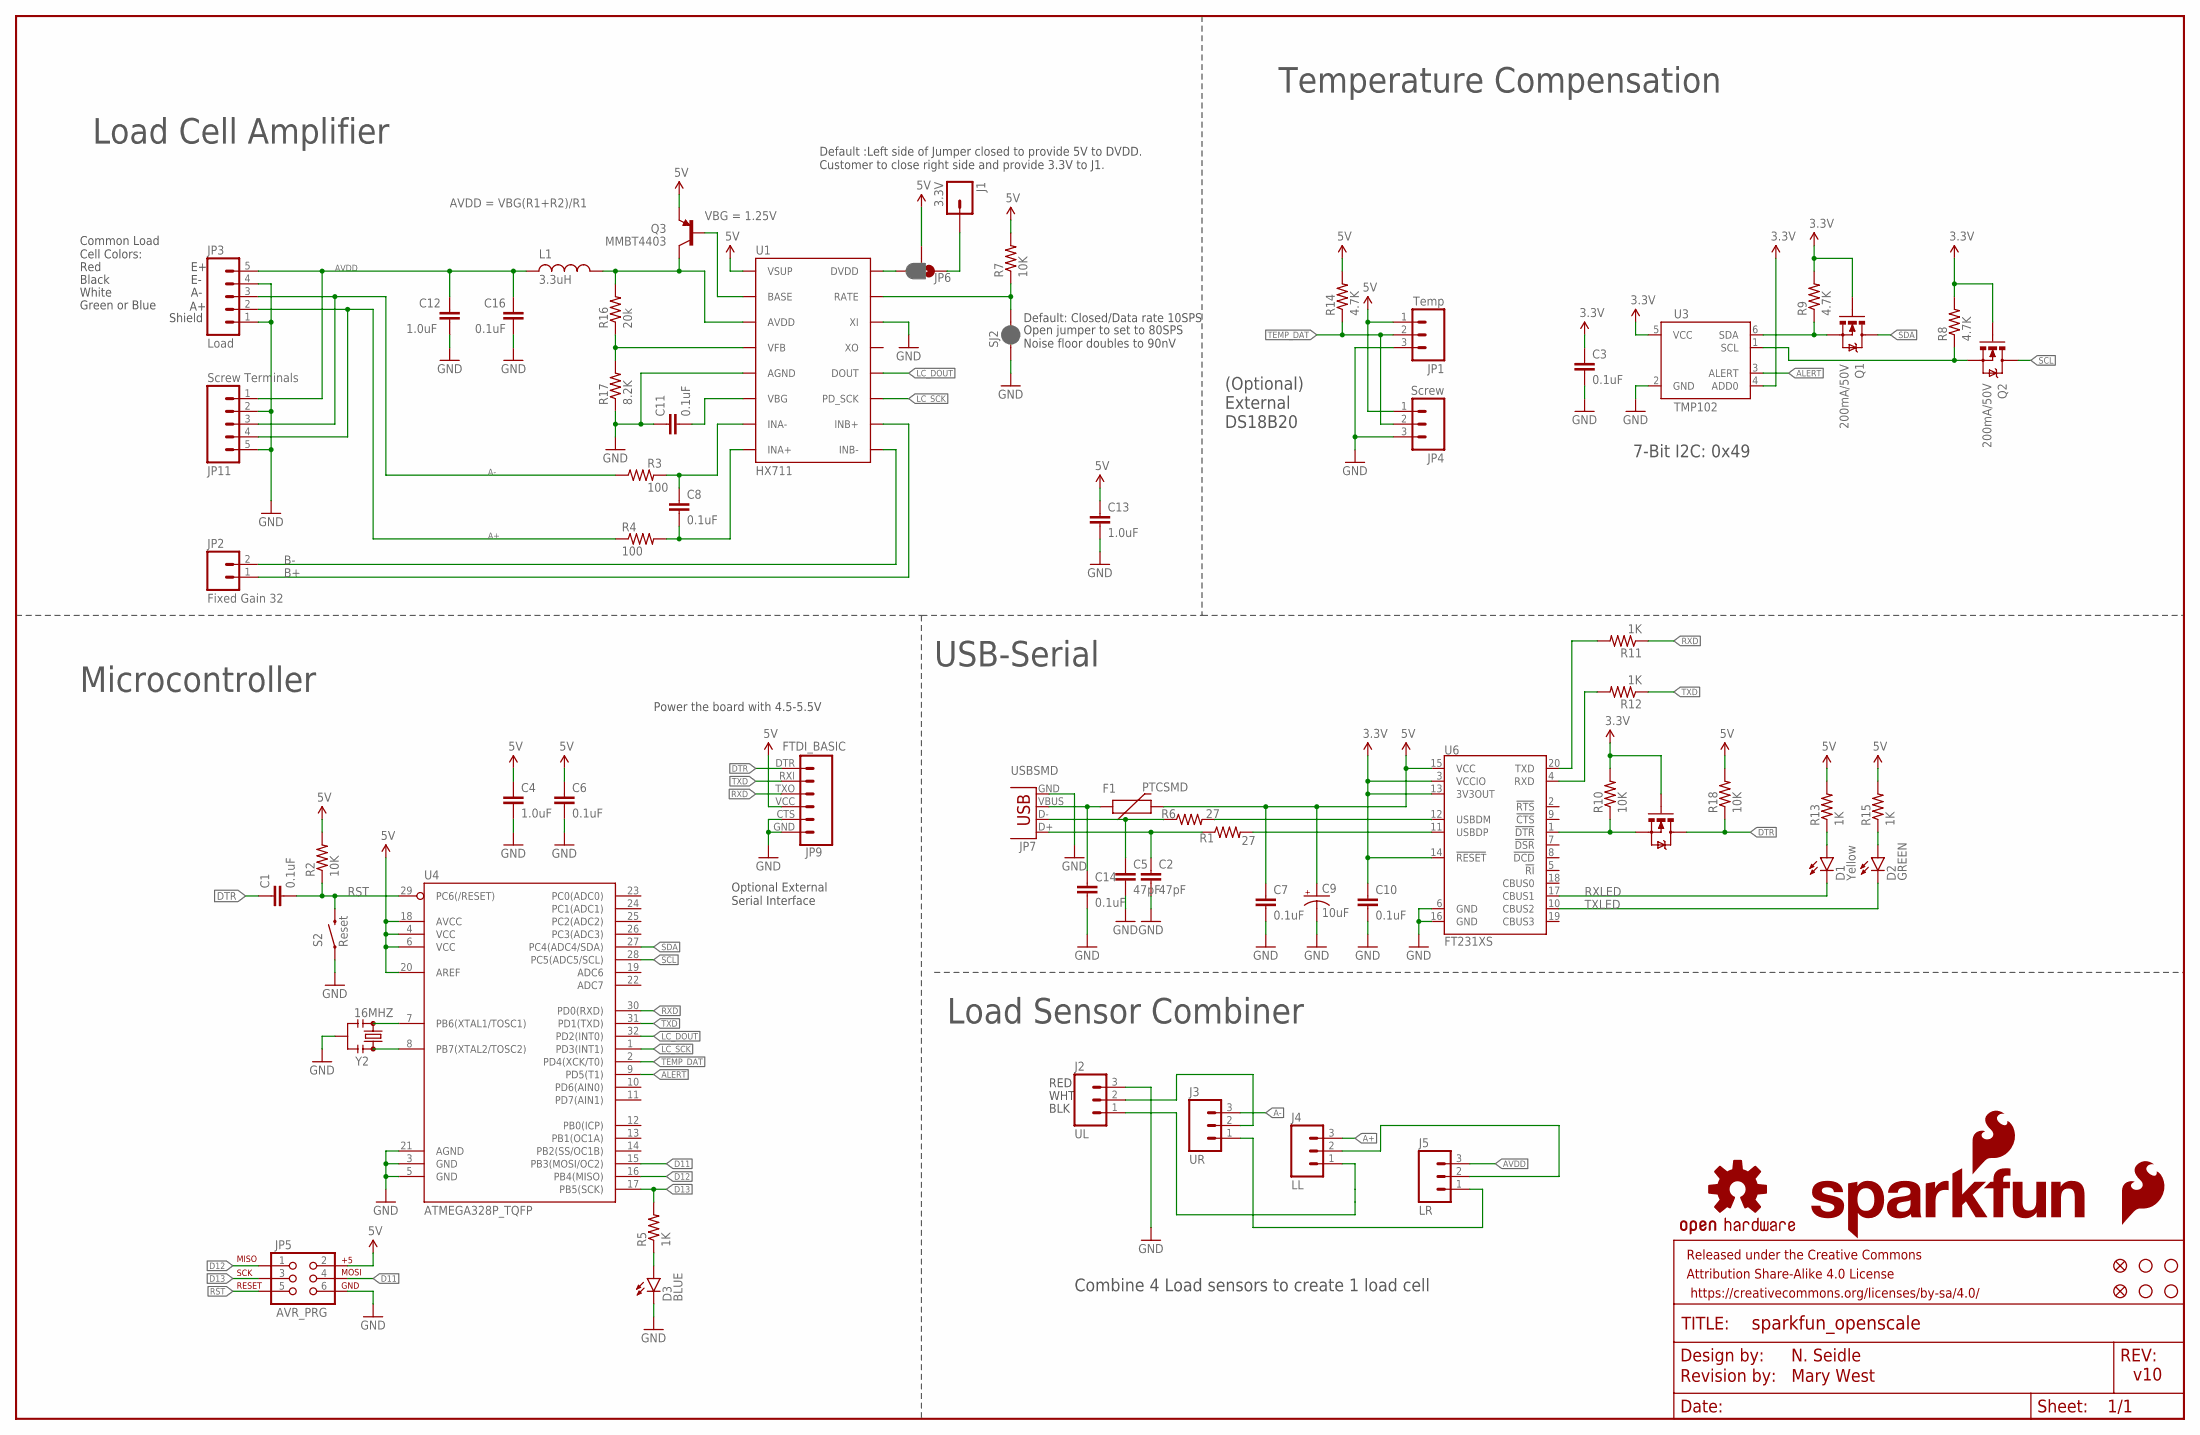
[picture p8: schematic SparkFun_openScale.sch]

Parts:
C1, C3, C6, C7, C8, C10, C11, C14, C16: 0.1uF; 0603-CAP
C2, C5: 47pF; 0603-CAP
C4, C12, C13: 1.0uF; 0603-CAP
C9: 10uF; EIA3216
D1: Yellow; LED-1206
D2: GREEN; LED-1206
D3: BLUE; LED-1206
F1: PTCSMD; PTC-1206
FID1, FID2: FIDUCIALUFIDUCIAL; MICRO-FIDUCIAL
FRAME1: FRAME-LEDGER; CREATIVE_COMMONS
J1: 3.3V; 1X01
J2: UL; 1X03
J3: UR; 1X03
J4: LL; 1X03
J5: LR; 1X03
JP1: Temp; 1X03_NO_SILK
JP2: Fixed Gain 32; 1X02
JP3: Load; 1X05_NO_SILK
JP4: Screw; SCREWTERMINAL-3.5MM-3_LOCK.007S
JP5: AVR_PRG; 2X3
JP6: JUMPER-PAD-3-2OF3_NC_BY_PASTE; PAD-JUMPER-3-2OF3_NC_BY_PASTE_YES_SILK_FULL_BOX
JP7: USBSMD; USB-MINIB
JP9: FTDI_BASIC
JP11: Screw Terminals; SCREWTERMINAL-3.5MM-5
L1: 3.3uH; 0805
LOGO2: OSHW-LOGOS; OSHW-LOGO-S
LOGO3: SFE_LOGO_FLAME.1_INCH; SFE_LOGO_FLAME_.1
LOGO4: SFE_LOGO_NAME_FLAME.1_INCH; SFE_LOGO_NAME_FLAME_.1
Q1, Q2: 200mA/50V; SOT23-3
Q3: MMBT4403; SOT23-3
Q4: MOSFET-NCHANNEL2N7002PW; SOT323
R1, R6: 27; 0603
R2, R7, R10, R18: 10K; 0603-RES
R3, R4: 100; 0603-RES
R5, R11, R12, R13, R15: 1K; 0603-RES
R8, R9, R14: 4.7K; 0603-RES
R16: 20k; 0603-RES
R17: 8.2K; 0603-RES
S2: Reset; TACTILE-SWITCH-SMD
SJ2: JUMPER-PAD-2-NC_BY_PASTE; PAD-JUMPER-2-NC_BY_PASTE_YES_SILK
STANDOFF1, STANDOFF2, STANDOFF3, STANDOFF4: STAND-OFF
U1: HX711; SO16
U3: TMP102; SOT563
U4: ATMEGA328P_TQFP; TQFP32-08
U6: FT231XS; SSOP20_L
Y2: 16MHZ; RESONATOR-SMD

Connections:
2: J4.2, J5.2
3.3V: C3.1, C10.1, Q1.1 (G), Q2.1 (G), Q4.1 (G), R8.2, R9.2, R10.2, U3.4 (ADD0), U3.5 (VCC), U6.3 (VCCIO), U6.13 (3V3OUT), U6.14 (!RESET)
5V: C4.1, C6.1, C7.1, C9.A (+), C13.1, F1.2, JP1.1, JP4.1, JP5.2, JP6.2, JP9.VCC (4), Q3.2 (E), R2.2, R7.2, R13.2, R14.2, R15.2, R18.2, U1.1 (VSUP), U4.4 (VCC), U4.6 (VCC), U4.18 (AVCC), U4.20 (AREF), U6.15 (VCC)
A+: J4.3, JP3.2, JP11.4, R4.1
A-: J3.3, JP3.3, JP11.3, R3.1
ALERT: U3.3 (ALERT), U4.9 (PD5(T1))
AVDD: C12.2, C16.1, J5.3, JP3.5, JP11.1, L1.1
B+: JP2.1, U1.10 (INB+)
B-: JP2.2, U1.9 (INB-)
D11: JP5.4, U4.15 (PB3(MOSI/OC2))
D12: JP5.1, U4.16 (PB4(MISO))
D13: JP5.3, R5.2, U4.17 (PB5(SCK))
DTR: C1.1, JP9.DTR (1), Q4.3 (D), R18.1
GND: C2.2, C3.2, C4.2, C5.2, C6.2, C7.2, C9.C (-), C10.2, C11.1, C12.1, C13.2, C14.2, C16.2, D3.C, J2.3, JP1.3, JP3.1, JP3.4, JP4.3, JP5.6, JP7.GND, JP9.CTS (5), JP9.GND (6), JP11.2, JP11.5, R17.1, S2.1, SJ2.1, U1.5 (AGND), U1.14 (XI), U3.2 (GND), U4.3 (GND), U4.5 (GND), U4.21 (AGND), U6.6 (GND), U6.16 (GND), Y2.2
LC_DOUT: U1.12 (DOUT), U4.32 (PD2(INT0))
LC_SCK: U1.11 (PD_SCK), U4.1 (PD3(INT1))
LV_SCL: Q2.2 (S), R8.1, U3.1 (SCL)
LV_SDA: Q1.2 (S), R9.1, U3.6 (SDA)
unnamed: U4.7 (PB6(XTAL1/TOSC1)), Y2.1
unnamed: D3.A, R5.1
unnamed: U4.8 (PB7(XTAL2/TOSC2)), Y2.3
unnamed: C5.1, JP7.D-, R6.1
unnamed: D1.A, R13.1
unnamed: D2.A, R15.1
unnamed: C2.1, JP7.D+, R1.1
unnamed: R6.2, U6.12 (USBDM)
unnamed: R7.1, SJ2.2, U1.15 (RATE)
unnamed: C8.1, R3.2, U1.7 (INA-)
unnamed: C8.2, R4.2, U1.8 (INA+)
unnamed: C14.1, F1.1, JP7.VBUS
unnamed: R1.2, U6.11 (USBDP)
unnamed: R12.2, U6.4 (RXD)
unnamed: JP6.3, U1.16 (DVDD)
unnamed: R11.2, U6.20 (TXD)
unnamed: Q3.1 (B), U1.2 (BASE)
unnamed: R16.1, R17.2, U1.4 (VFB)
unnamed: J1.1, JP6.1
unnamed: J2.2, J3.2
unnamed: C11.2, U1.6 (VBG)
unnamed: J2.1, J4.1
unnamed: J3.1, J5.1
unnamed: Q4.2 (S), R10.1, U6.1 (!DTR)
RIPUP@: L1.2, Q3.3 (C), R16.2, U1.3 (AVDD)
RST: C1.2, JP5.5, R2.1, S2.3 (2), U4.29 (PC6(/RESET))
RXD: JP9.TXO (3), R11.1, U4.30 (PD0(RXD))
RXLED: D1.C, U6.17 (CBUS1)
SCL: Q2.3 (D), U4.28 (PC5(ADC5/SCL))
SDA: Q1.3 (D), U4.27 (PC4(ADC4/SDA))
TEMP_DAT: JP1.2, JP4.2, R14.1, U4.2 (PD4(XCK/T0))
TXD: JP9.RXI (2), R12.1, U4.31 (PD1(TXD))
TXLED: D2.C, U6.10 (CBUS2)

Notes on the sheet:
Microcontroller
USB-Serial
Default: Closed/Data rate 10SPS
Open jumper to set to 80SPS Noise floor doubles to 90nV
Red
Black
White
Green or Blue
Common Load Cell Colors:
Temperature Compensation
(Optional) External DS18B20
Load Cell Amplifier
7-Bit I2C: 0x49
Shield
Optional External Serial Interface
VBG = 1.25V
AVDD = VBG(R1+R2)/R1
v10
N. Seidle
Power the board with 4.5-5.5V
RED
WHT
BLK
Combine 4 Load sensors to create 1 load cell
Load Sensor Combiner
Default :Left side of Jumper closed to provide 5V to DVDD. Customer to close right side and provide 3.3V to J1.
Revision by: Mary West

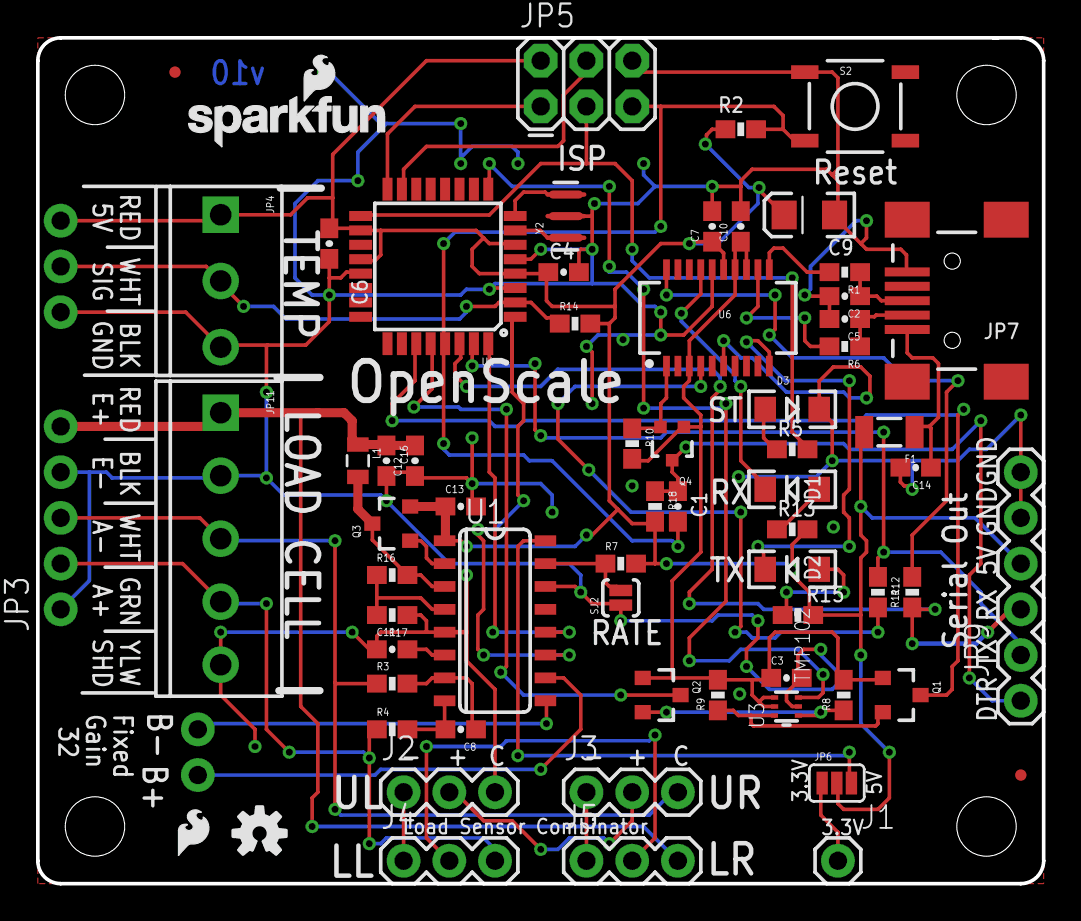
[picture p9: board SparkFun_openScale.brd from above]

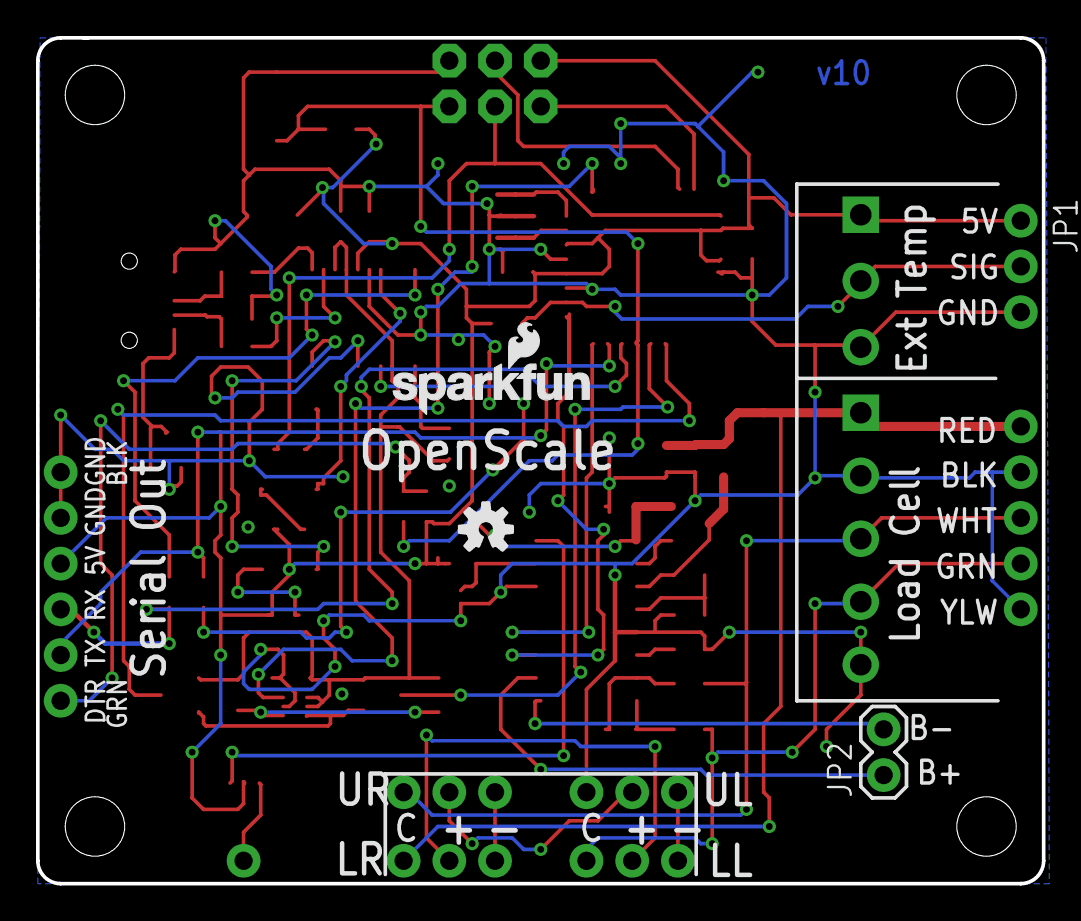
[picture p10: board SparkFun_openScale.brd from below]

Board: 2 copper layers, 55.9 x 47.0 mm, 75 parts (4 on the bottom side), 51 nets.

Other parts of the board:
LOGO1: SFE_LOGO_NAME_FLAME.1_INCH; SFE_LOGO_NAME_FLAME_.1
LOGO5: OSHW-LOGOS; OSHW-LOGO-S

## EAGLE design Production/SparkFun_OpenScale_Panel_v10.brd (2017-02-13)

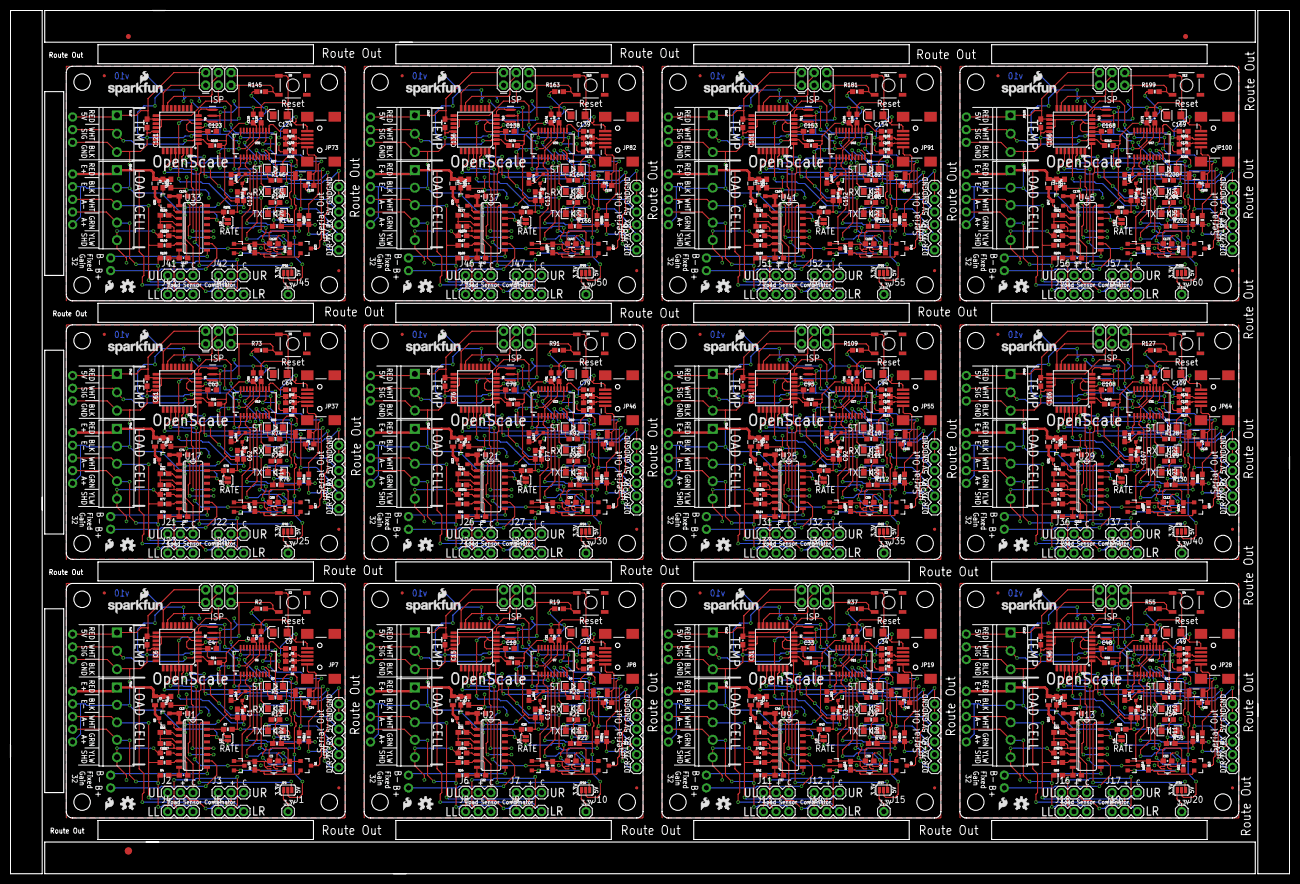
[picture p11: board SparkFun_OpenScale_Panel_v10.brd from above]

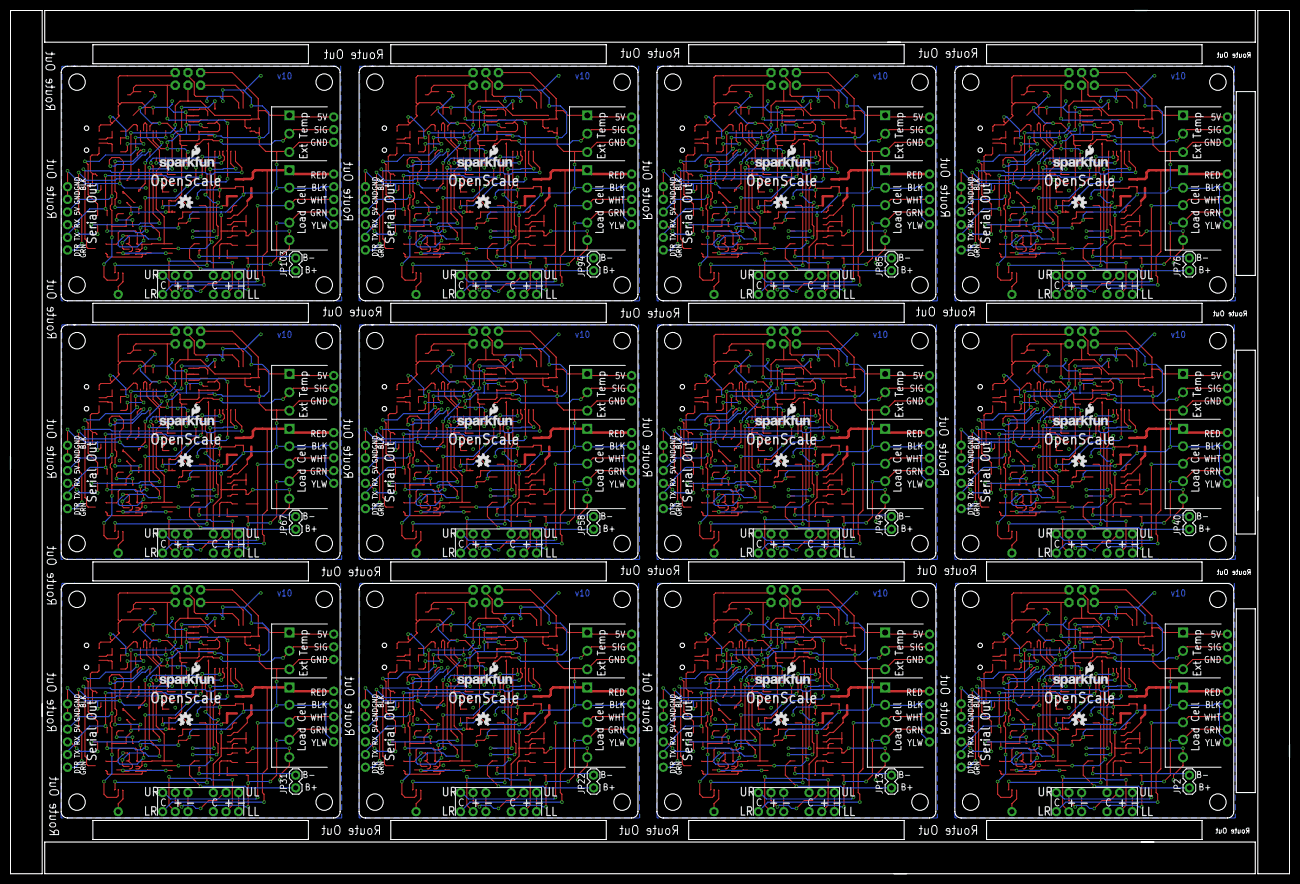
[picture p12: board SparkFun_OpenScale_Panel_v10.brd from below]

Board: 2 copper layers, 256.3 x 173.0 mm, 891 parts (48 on the bottom side), 612 nets.

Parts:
C1, C3, C6, C7, C8, C10, C11, C14, C15, C16, C17, C20, C21, C22, C23, C24, C27, C30, C31, C32, C35, C36, C37, C38, C39, C42, C45, C46, C47, C50, C51, C52, C53, C54, C57, C60, C61, C62, C65, C66, C67, C68, C69, C72, C75, C76, C77, C80, C81, C82, C83, C84, C87, C90, C91, C92, C95, C96, C97, C98, C99, C102, C105, C106, C107, C110, C111, C112, C113, C114, C117, C120, C121, C122, C125, C126, C127, C128, C129, C132, C135, C136, C137, C140, C141, C142, C143, C144, C147, C150, C151, C152, C155, C156, C157, C158, C159, C162, C165, C166, C167, C170, C171, C172, C173, C174, C177, C180: 0.1uF; 0603-CAP
C2, C5, C25, C26, C40, C41, C55, C56, C70, C71, C85, C86, C100, C101, C115, C116, C130, C131, C145, C146, C160, C161, C175, C176: 47pF; 0603-CAP
C4, C12, C13, C18, C28, C29, C33, C43, C44, C48, C58, C59, C63, C73, C74, C78, C88, C89, C93, C103, C104, C108, C118, C119, C123, C133, C134, C138, C148, C149, C153, C163, C164, C168, C178, C179: 1.0uF; 0603-CAP
C9, C19, C34, C49, C64, C79, C94, C109, C124, C139, C154, C169: 10uF; EIA3216
D1, D4, D7, D10, D13, D16, D19, D22, D25, D28, D31, D34: Yellow; LED-1206
D2, D5, D8, D11, D14, D17, D20, D23, D26, D29, D32, D35: GREEN; LED-1206
D3, D6, D9, D12, D15, D18, D21, D24, D27, D30, D33, D36: BLUE; LED-1206
E$1: FIDUCIAL-1.5X3
E$7, E$8: FIDUCIAL-1X2
F1, F2, F3, F4, F5, F6, F7, F8, F9, F10, F11, F12: PTCSMD; PTC-1206
FID1, FID2, FID3, FID4, FID5, FID6, FID7, FID8, FID9, FID10, FID11, FID12, FID13, FID14, FID15, FID16, FID17, FID18, FID19, FID20, FID21, FID22, FID23, FID24: FIDUCIALUFIDUCIAL; MICRO-FIDUCIAL
J1, J10, J15, J20, J25, J30, J35, J40, J45, J50, J55, J60: 3.3V; 1X01
J2, J6, J11, J16, J21, J26, J31, J36, J41, J46, J51, J56: UL; 1X03
J3, J7, J12, J17, J22, J27, J32, J37, J42, J47, J52, J57: UR; 1X03
J4, J8, J13, J18, J23, J28, J33, J38, J43, J48, J53, J58: LL; 1X03
J5, J9, J14, J19, J24, J29, J34, J39, J44, J49, J54, J59: LR; 1X03
JP1, JP12, JP21, JP30, JP39, JP48, JP57, JP66, JP75, JP84, JP93, JP102: Temp; 1X03_NO_SILK
JP2, JP13, JP22, JP31, JP40, JP49, JP58, JP67, JP76, JP85, JP94, JP103: Fixed Gain 32; 1X02
JP3, JP16, JP25, JP34, JP43, JP52, JP61, JP70, JP79, JP88, JP97, JP106: Load; 1X05_NO_SILK
JP4, JP15, JP24, JP33, JP42, JP51, JP60, JP69, JP78, JP87, JP96, JP105: Screw; SCREWTERMINAL-3.5MM-3_LOCK.007S
JP5, JP10, JP20, JP29, JP38, JP47, JP56, JP65, JP74, JP83, JP92, JP101: AVR_PRG; 2X3
JP6, JP18, JP27, JP36, JP45, JP54, JP63, JP72, JP81, JP90, JP99, JP108: JUMPER-PAD-3-2OF3_NC_BY_PASTE; PAD-JUMPER-3-2OF3_NC_BY_PASTE_YES_SILK_FULL_BOX
JP7, JP8, JP19, JP28, JP37, JP46, JP55, JP64, JP73, JP82, JP91, JP100: USBSMD; USB-MINIB
JP9, JP14, JP23, JP32, JP41, JP50, JP59, JP68, JP77, JP86, JP95, JP104: FTDI_BASIC
JP11, JP17, JP26, JP35, JP44, JP53, JP62, JP71, JP80, JP89, JP98, JP107: Screw Terminals; SCREWTERMINAL-3.5MM-5
L1, L2, L3, L4, L5, L6, L7, L8, L9, L10, L11, L12: 3.3uH; 0805
LOGO1, LOGO4, LOGO7, LOGO9, LOGO12, LOGO14, LOGO17, LOGO19, LOGO22, LOGO24, LOGO27, LOGO29, LOGO32, LOGO34, LOGO37, LOGO39, LOGO42, LOGO44, LOGO47, LOGO49, LOGO52, LOGO54, LOGO57, LOGO59: SFE_LOGO_NAME_FLAME.1_INCH; SFE_LOGO_NAME_FLAME_.1
LOGO2, LOGO5, LOGO6, LOGO10, LOGO11, LOGO15, LOGO16, LOGO20, LOGO21, LOGO25, LOGO26, LOGO30, LOGO31, LOGO35, LOGO36, LOGO40, LOGO41, LOGO45, LOGO46, LOGO50, LOGO51, LOGO55, LOGO56, LOGO60: OSHW-LOGOS; OSHW-LOGO-S
LOGO3, LOGO8, LOGO13, LOGO18, LOGO23, LOGO28, LOGO33, LOGO38, LOGO43, LOGO48, LOGO53, LOGO58: SFE_LOGO_FLAME.1_INCH; SFE_LOGO_FLAME_.1
Q1, Q2, Q5, Q6, Q9, Q10, Q13, Q14, Q17, Q18, Q21, Q22, Q25, Q26, Q29, Q30, Q33, Q34, Q37, Q38, Q41, Q42, Q45, Q46: 200mA/50V; SOT23-3
Q3, Q7, Q11, Q15, Q19, Q23, Q27, Q31, Q35, Q39, Q43, Q47: MMBT4403; SOT23-3
Q4, Q8, Q12, Q16, Q20, Q24, Q28, Q32, Q36, Q40, Q44, Q48: MOSFET-NCHANNEL2N7002PW; SOT323
R1, R6, R28, R29, R46, R47, R64, R65, R82, R83, R100, R101, R118, R119, R136, R137, R154, R155, R172, R173, R190, R191, R208, R209: 27; 0603
R2, R7, R10, R18, R19, R25, R35, R36, R37, R43, R53, R54, R55, R61, R71, R72, R73, R79, R89, R90, R91, R97, R107, R108, R109, R115, R125, R126, R127, R133, R143, R144, R145, R151, R161, R162, R163, R169, R179, R180, R181, R187, R197, R198, R199, R205, R215, R216: 10K; 0603-RES
R3, R4, R23, R24, R41, R42, R59, R60, R77, R78, R95, R96, R113, R114, R131, R132, R149, R150, R167, R168, R185, R186, R203, R204: 100; 0603-RES
R5, R11, R12, R13, R15, R20, R21, R22, R30, R31, R38, R39, R40, R48, R49, R56, R57, R58, R66, R67, R74, R75, R76, R84, R85, R92, R93, R94, R102, R103, R110, R111, R112, R120, R121, R128, R129, R130, R138, R139, R146, R147, R148, R156, R157, R164, R165, R166, R174, R175, R182, R183, R184, R192, R193, R200, R201, R202, R210, R211: 1K; 0603-RES
R8, R9, R14, R26, R27, R32, R44, R45, R50, R62, R63, R68, R80, R81, R86, R98, R99, R104, R116, R117, R122, R134, R135, R140, R152, R153, R158, R170, R171, R176, R188, R189, R194, R206, R207, R212: 4.7K; 0603-RES
R16, R33, R51, R69, R87, R105, R123, R141, R159, R177, R195, R213: 20k; 0603-RES
R17, R34, R52, R70, R88, R106, R124, R142, R160, R178, R196, R214: 8.2K; 0603-RES
S1, S2, S3, S4, S5, S6, S7, S8, S9, S10, S11, S12: Reset; TACTILE-SWITCH-SMD
SJ1, SJ2, SJ3, SJ4, SJ5, SJ6, SJ7, SJ8, SJ9, SJ10, SJ11, SJ12: JUMPER-PAD-2-NC_BY_PASTE; PAD-JUMPER-2-NC_BY_PASTE_YES_SILK
STANDOFF1, STANDOFF2, STANDOFF3, STANDOFF4, STANDOFF5, STANDOFF6, STANDOFF7, STANDOFF8, STANDOFF9, STANDOFF10, STANDOFF11, STANDOFF12, STANDOFF13, STANDOFF14, STANDOFF15, STANDOFF16, STANDOFF17, STANDOFF18, STANDOFF19, STANDOFF20, STANDOFF21, STANDOFF22, STANDOFF23, STANDOFF24, STANDOFF25, STANDOFF26, STANDOFF27, STANDOFF28, STANDOFF29, STANDOFF30, STANDOFF31, STANDOFF32, STANDOFF33, STANDOFF34, STANDOFF35, STANDOFF36, STANDOFF37, STANDOFF38, STANDOFF39, STANDOFF40, STANDOFF41, STANDOFF42, STANDOFF43, STANDOFF44, STANDOFF45, STANDOFF46, STANDOFF47, STANDOFF48: STAND-OFF
U1, U2, U9, U13, U17, U21, U25, U29, U33, U37, U41, U45: HX711; SO16
U3, U5, U10, U14, U18, U22, U26, U30, U34, U38, U42, U46: TMP102; SOT563
U4, U8, U12, U16, U20, U24, U28, U32, U36, U40, U44, U48: ATMEGA328P_TQFP; TQFP32-08
U6, U7, U11, U15, U19, U23, U27, U31, U35, U39, U43, U47: FT231XS; SSOP20_L
Y1, Y2, Y3, Y4, Y5, Y6, Y7, Y8, Y9, Y10, Y11, Y12: 16MHZ; RESONATOR-SMD

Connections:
1: J8.2, J9.2
2: J4.2, J5.2
3: J13.2, J14.2
3.3V: C3.1, C10.1, Q1.1, Q2.1, Q4.1, R8.2, R9.2, R10.2, U3.4, U3.5, U6.3, U6.13, U6.14
3.3V1: C20.1, C23.1, Q5.1, Q6.1, Q8.1, R26.2, R27.2, R35.2, U5.4, U5.5, U7.3, U7.13, U7.14
3.3V2: C35.1, C38.1, Q9.1, Q10.1, Q12.1, R44.2, R45.2, R53.2, U10.4, U10.5, U11.3, U11.13, U11.14
3.3V3: C50.1, C53.1, Q13.1, Q14.1, Q16.1, R62.2, R63.2, R71.2, U14.4, U14.5, U15.3, U15.13, U15.14
3.3V4: C65.1, C68.1, Q17.1, Q18.1, Q20.1, R80.2, R81.2, R89.2, U18.4, U18.5, U19.3, U19.13, U19.14
3.3V5: C80.1, C83.1, Q21.1, Q22.1, Q24.1, R98.2, R99.2, R107.2, U22.4, U22.5, U23.3, U23.13, U23.14
3.3V6: C95.1, C98.1, Q25.1, Q26.1, Q28.1, R116.2, R117.2, R125.2, U26.4, U26.5, U27.3, U27.13, U27.14
3.3V7: C110.1, C113.1, Q29.1, Q30.1, Q32.1, R134.2, R135.2, R143.2, U30.4, U30.5, U31.3, U31.13, U31.14
3.3V8: C125.1, C128.1, Q33.1, Q34.1, Q36.1, R152.2, R153.2, R161.2, U34.4, U34.5, U35.3, U35.13, U35.14
3.3V9: C140.1, C143.1, Q37.1, Q38.1, Q40.1, R170.2, R171.2, R179.2, U38.4, U38.5, U39.3, U39.13, U39.14
3.3V10: C155.1, C158.1, Q41.1, Q42.1, Q44.1, R188.2, R189.2, R197.2, U42.4, U42.5, U43.3, U43.13, U43.14
3.3V11: C170.1, C173.1, Q45.1, Q46.1, Q48.1, R206.2, R207.2, R215.2, U46.4, U46.5, U47.3, U47.13, U47.14
4: J18.2, J19.2
5: J23.2, J24.2
5V: C4.1, C6.1, C7.1, C9.A, C13.1, F1.2, JP1.1, JP4.1, JP5.2, JP6.2, JP9.VCC, Q3.2, R2.2, R7.2, R13.2, R14.2, R15.2, R18.2, U1.1, U4.4, U4.6, U4.18, U4.20, U6.15
5V1: C15.1, C18.1, C19.A, C21.1, C29.1, F2.2, JP10.2, JP12.1, JP14.VCC, JP15.1, JP18.2, Q7.2, R19.2, R21.2, R22.2, R25.2, R32.2, R36.2, U2.1, U7.15, U8.4, U8.6, U8.18, U8.20
5V2: C31.1, C33.1, C34.A, C36.1, C44.1, F3.2, JP20.2, JP21.1, JP23.VCC, JP24.1, JP27.2, Q11.2, R37.2, R39.2, R40.2, R43.2, R50.2, R54.2, U9.1, U11.15, U12.4, U12.6, U12.18, U12.20
5V3: C46.1, C48.1, C49.A, C51.1, C59.1, F4.2, JP29.2, JP30.1, JP32.VCC, JP33.1, JP36.2, Q15.2, R55.2, R57.2, R58.2, R61.2, R68.2, R72.2, U13.1, U15.15, U16.4, U16.6, U16.18, U16.20
5V4: C61.1, C63.1, C64.A, C66.1, C74.1, F5.2, JP38.2, JP39.1, JP41.VCC, JP42.1, JP45.2, Q19.2, R73.2, R75.2, R76.2, R79.2, R86.2, R90.2, U17.1, U19.15, U20.4, U20.6, U20.18, U20.20
5V5: C76.1, C78.1, C79.A, C81.1, C89.1, F6.2, JP47.2, JP48.1, JP50.VCC, JP51.1, JP54.2, Q23.2, R91.2, R93.2, R94.2, R97.2, R104.2, R108.2, U21.1, U23.15, U24.4, U24.6, U24.18, U24.20
5V6: C91.1, C93.1, C94.A, C96.1, C104.1, F7.2, JP56.2, JP57.1, JP59.VCC, JP60.1, JP63.2, Q27.2, R109.2, R111.2, R112.2, R115.2, R122.2, R126.2, U25.1, U27.15, U28.4, U28.6, U28.18, U28.20
5V7: C106.1, C108.1, C109.A, C111.1, C119.1, F8.2, JP65.2, JP66.1, JP68.VCC, JP69.1, JP72.2, Q31.2, R127.2, R129.2, R130.2, R133.2, R140.2, R144.2, U29.1, U31.15, U32.4, U32.6, U32.18, U32.20
5V8: C121.1, C123.1, C124.A, C126.1, C134.1, F9.2, JP74.2, JP75.1, JP77.VCC, JP78.1, JP81.2, Q35.2, R145.2, R147.2, R148.2, R151.2, R158.2, R162.2, U33.1, U35.15, U36.4, U36.6, U36.18, U36.20
5V9: C136.1, C138.1, C139.A, C141.1, C149.1, F10.2, JP83.2, JP84.1, JP86.VCC, JP87.1, JP90.2, Q39.2, R163.2, R165.2, R166.2, R169.2, R176.2, R180.2, U37.1, U39.15, U40.4, U40.6, U40.18, U40.20
5V10: C151.1, C153.1, C154.A, C156.1, C164.1, F11.2, JP92.2, JP93.1, JP95.VCC, JP96.1, JP99.2, Q43.2, R181.2, R183.2, R184.2, R187.2, R194.2, R198.2, U41.1, U43.15, U44.4, U44.6, U44.18, U44.20
5V11: C166.1, C168.1, C169.A, C171.1, C179.1, F12.2, JP101.2, JP102.1, JP104.VCC, JP105.1, JP108.2, Q47.2, R199.2, R201.2, R202.2, R205.2, R212.2, R216.2, U45.1, U47.15, U48.4, U48.6, U48.18, U48.20
6: J28.2, J29.2
7: J33.2, J34.2
8: J38.2, J39.2
9: J43.2, J44.2
10: J48.2, J49.2
11: J53.2, J54.2
12: J58.2, J59.2
A+: J4.3, JP3.2, JP11.4, R4.1
A+1: J8.3, JP16.2, JP17.4, R24.1
A+2: J13.3, JP25.2, JP26.4, R42.1
A+3: J18.3, JP34.2, JP35.4, R60.1
A+4: J23.3, JP43.2, JP44.4, R78.1
A+5: J28.3, JP52.2, JP53.4, R96.1
A+6: J33.3, JP61.2, JP62.4, R114.1
A+7: J38.3, JP70.2, JP71.4, R132.1
A+8: J43.3, JP79.2, JP80.4, R150.1
A+9: J48.3, JP88.2, JP89.4, R168.1
A+10: J53.3, JP97.2, JP98.4, R186.1
A+11: J58.3, JP106.2, JP107.4, R204.1
A-: J3.3, JP3.3, JP11.3, R3.1
A-1: J7.3, JP16.3, JP17.3, R23.1
A-2: J12.3, JP25.3, JP26.3, R41.1
A-3: J17.3, JP34.3, JP35.3, R59.1
A-4: J22.3, JP43.3, JP44.3, R77.1
A-5: J27.3, JP52.3, JP53.3, R95.1
A-6: J32.3, JP61.3, JP62.3, R113.1
A-7: J37.3, JP70.3, JP71.3, R131.1
A-8: J42.3, JP79.3, JP80.3, R149.1
A-9: J47.3, JP88.3, JP89.3, R167.1
A-10: J52.3, JP97.3, JP98.3, R185.1
A-11: J57.3, JP106.3, JP107.3, R203.1
ALERT: U3.3, U4.9
ALERT1: U5.3, U8.9
ALERT2: U10.3, U12.9
ALERT3: U14.3, U16.9
ALERT4: U18.3, U20.9
ALERT5: U22.3, U24.9
ALERT6: U26.3, U28.9
ALERT7: U30.3, U32.9
ALERT8: U34.3, U36.9
ALERT9: U38.3, U40.9
ALERT10: U42.3, U44.9
ALERT11: U46.3, U48.9
AVDD: C12.2, C16.1, J5.3, JP3.5, JP11.1, L1.1
AVDD1: C24.1, C28.2, J9.3, JP16.5, JP17.1, L2.1
AVDD2: C39.1, C43.2, J14.3, JP25.5, JP26.1, L3.1
AVDD3: C54.1, C58.2, J19.3, JP34.5, JP35.1, L4.1
AVDD4: C69.1, C73.2, J24.3, JP43.5, JP44.1, L5.1
AVDD5: C84.1, C88.2, J29.3, JP52.5, JP53.1, L6.1
AVDD6: C99.1, C103.2, J34.3, JP61.5, JP62.1, L7.1
AVDD7: C114.1, C118.2, J39.3, JP70.5, JP71.1, L8.1
AVDD8: C129.1, C133.2, J44.3, JP79.5, JP80.1, L9.1
AVDD9: C144.1, C148.2, J49.3, JP88.5, JP89.1, L10.1
AVDD10: C159.1, C163.2, J54.3, JP97.5, JP98.1, L11.1
AVDD11: C174.1, C178.2, J59.3, JP106.5, JP107.1, L12.1
B+: JP2.1, U1.10
B+1: JP13.1, U2.10
B+2: JP22.1, U9.10
B+3: JP31.1, U13.10
B+4: JP40.1, U17.10
B+5: JP49.1, U21.10
B+6: JP58.1, U25.10
B+7: JP67.1, U29.10
B+8: JP76.1, U33.10
B+9: JP85.1, U37.10
B+10: JP94.1, U41.10
B+11: JP103.1, U45.10
B-: JP2.2, U1.9
B-1: JP13.2, U2.9
B-2: JP22.2, U9.9
B-3: JP31.2, U13.9
B-4: JP40.2, U17.9
B-5: JP49.2, U21.9
B-6: JP58.2, U25.9
B-7: JP67.2, U29.9
B-8: JP76.2, U33.9
B-9: JP85.2, U37.9
B-10: JP94.2, U41.9
B-11: JP103.2, U45.9
D1: JP10.4, U8.15
D2: JP10.1, U8.16
D3: JP10.3, R20.2, U8.17
D4: JP20.4, U12.15
D5: JP20.1, U12.16
D6: JP20.3, R38.2, U12.17
D7: JP29.4, U16.15
D8: JP29.1, U16.16
D9: JP29.3, R56.2, U16.17
D10: JP38.4, U20.15
D11: JP5.4, U4.15
D12: JP5.1, U4.16
D13: JP5.3, R5.2, U4.17
D14: JP38.1, U20.16
D15: JP38.3, R74.2, U20.17
D16: JP47.4, U24.15
D17: JP47.1, U24.16
D18: JP47.3, R92.2, U24.17
D19: JP56.4, U28.15
D20: JP56.1, U28.16
D21: JP56.3, R110.2, U28.17
D22: JP65.4, U32.15
D23: JP65.1, U32.16
D24: JP65.3, R128.2, U32.17
D25: JP74.4, U36.15
D26: JP74.1, U36.16
D27: JP74.3, R146.2, U36.17
D28: JP83.4, U40.15
D29: JP83.1, U40.16
D30: JP83.3, R164.2, U40.17
D31: JP92.4, U44.15
D32: JP92.1, U44.16
D33: JP92.3, R182.2, U44.17
D34: JP101.4, U48.15
D35: JP101.1, U48.16
D36: JP101.3, R200.2, U48.17
DTR: C1.1, JP9.DTR, Q4.3, R18.1
DTR1: C17.1, JP14.DTR, Q8.3, R36.1
DTR2: C32.1, JP23.DTR, Q12.3, R54.1
DTR3: C47.1, JP32.DTR, Q16.3, R72.1
DTR4: C62.1, JP41.DTR, Q20.3, R90.1
DTR5: C77.1, JP50.DTR, Q24.3, R108.1
DTR6: C92.1, JP59.DTR, Q28.3, R126.1
DTR7: C107.1, JP68.DTR, Q32.3, R144.1
DTR8: C122.1, JP77.DTR, Q36.3, R162.1
DTR9: C137.1, JP86.DTR, Q40.3, R180.1
DTR10: C152.1, JP95.DTR, Q44.3, R198.1
DTR11: C167.1, JP104.DTR, Q48.3, R216.1
GND: C2.2, C3.2, C4.2, C5.2, C6.2, C7.2, C9.C, C10.2, C11.1, C12.1, C13.2, C14.2, C16.2, D3.C, J2.3, JP1.3, JP3.1, JP3.4, JP4.3, JP5.6, JP7.GND, JP9.CTS, JP9.GND, JP11.2, JP11.5, R17.1, S2.1, SJ2.1, U1.5, U1.14, U3.2, U4.3, U4.5, U4.21, U6.6, U6.16, Y2.2
GND1: C15.2, C18.2, C19.C, C20.2, C21.2, C23.2, C24.2, C25.2, C26.2, C27.1, C28.1, C29.2, C30.2, D6.C, J6.3, JP8.GND, JP10.6, JP12.3, JP14.CTS, JP14.GND, JP15.3, JP16.1, JP16.4, JP17.2, JP17.5, R34.1, S1.1, SJ1.1, U2.5, U2.14, U5.2, U7.6, U7.16, U8.3, U8.5, U8.21, Y1.2
GND2: C31.2, C33.2, C34.C, C35.2, C36.2, C38.2, C39.2, C40.2, C41.2, C42.1, C43.1, C44.2, C45.2, D9.C, J11.3, JP19.GND, JP20.6, JP21.3, JP23.CTS, JP23.GND, JP24.3, JP25.1, JP25.4, JP26.2, JP26.5, R52.1, S3.1, SJ3.1, U9.5, U9.14, U10.2, U11.6, U11.16, U12.3, U12.5, U12.21, Y3.2
GND3: C46.2, C48.2, C49.C, C50.2, C51.2, C53.2, C54.2, C55.2, C56.2, C57.1, C58.1, C59.2, C60.2, D12.C, J16.3, JP28.GND, JP29.6, JP30.3, JP32.CTS, JP32.GND, JP33.3, JP34.1, JP34.4, JP35.2, JP35.5, R70.1, S4.1, SJ4.1, U13.5, U13.14, U14.2, U15.6, U15.16, U16.3, U16.5, U16.21, Y4.2
GND4: C61.2, C63.2, C64.C, C65.2, C66.2, C68.2, C69.2, C70.2, C71.2, C72.1, C73.1, C74.2, C75.2, D15.C, J21.3, JP37.GND, JP38.6, JP39.3, JP41.CTS, JP41.GND, JP42.3, JP43.1, JP43.4, JP44.2, JP44.5, R88.1, S5.1, SJ5.1, U17.5, U17.14, U18.2, U19.6, U19.16, U20.3, U20.5, U20.21, Y5.2
GND5: C76.2, C78.2, C79.C, C80.2, C81.2, C83.2, C84.2, C85.2, C86.2, C87.1, C88.1, C89.2, C90.2, D18.C, J26.3, JP46.GND, JP47.6, JP48.3, JP50.CTS, JP50.GND, JP51.3, JP52.1, JP52.4, JP53.2, JP53.5, R106.1, S6.1, SJ6.1, U21.5, U21.14, U22.2, U23.6, U23.16, U24.3, U24.5, U24.21, Y6.2
GND6: C91.2, C93.2, C94.C, C95.2, C96.2, C98.2, C99.2, C100.2, C101.2, C102.1, C103.1, C104.2, C105.2, D21.C, J31.3, JP55.GND, JP56.6, JP57.3, JP59.CTS, JP59.GND, JP60.3, JP61.1, JP61.4, JP62.2, JP62.5, R124.1, S7.1, SJ7.1, U25.5, U25.14, U26.2, U27.6, U27.16, U28.3, U28.5, U28.21, Y7.2
GND7: C106.2, C108.2, C109.C, C110.2, C111.2, C113.2, C114.2, C115.2, C116.2, C117.1, C118.1, C119.2, C120.2, D24.C, J36.3, JP64.GND, JP65.6, JP66.3, JP68.CTS, JP68.GND, JP69.3, JP70.1, JP70.4, JP71.2, JP71.5, R142.1, S8.1, SJ8.1, U29.5, U29.14, U30.2, U31.6, U31.16, U32.3, U32.5, U32.21, Y8.2
GND8: C121.2, C123.2, C124.C, C125.2, C126.2, C128.2, C129.2, C130.2, C131.2, C132.1, C133.1, C134.2, C135.2, D27.C, J41.3, JP73.GND, JP74.6, JP75.3, JP77.CTS, JP77.GND, JP78.3, JP79.1, JP79.4, JP80.2, JP80.5, R160.1, S9.1, SJ9.1, U33.5, U33.14, U34.2, U35.6, U35.16, U36.3, U36.5, U36.21, Y9.2
GND9: C136.2, C138.2, C139.C, C140.2, C141.2, C143.2, C144.2, C145.2, C146.2, C147.1, C148.1, C149.2, C150.2, D30.C, J46.3, JP82.GND, JP83.6, JP84.3, JP86.CTS, JP86.GND, JP87.3, JP88.1, JP88.4, JP89.2, JP89.5, R178.1, S10.1, SJ10.1, U37.5, U37.14, U38.2, U39.6, U39.16, U40.3, U40.5, U40.21, Y10.2
GND10: C151.2, C153.2, C154.C, C155.2, C156.2, C158.2, C159.2, C160.2, C161.2, C162.1, C163.1, C164.2, C165.2, D33.C, J51.3, JP91.GND, JP92.6, JP93.3, JP95.CTS, JP95.GND, JP96.3, JP97.1, JP97.4, JP98.2, JP98.5, R196.1, S11.1, SJ11.1, U41.5, U41.14, U42.2, U43.6, U43.16, U44.3, U44.5, U44.21, Y11.2
GND11: C166.2, C168.2, C169.C, C170.2, C171.2, C173.2, C174.2, C175.2, C176.2, C177.1, C178.1, C179.2, C180.2, D36.C, J56.3, JP100.GND, JP101.6, JP102.3, JP104.CTS, JP104.GND, JP105.3, JP106.1, JP106.4, JP107.2, JP107.5, R214.1, S12.1, SJ12.1, U45.5, U45.14, U46.2, U47.6, U47.16, U48.3, U48.5, U48.21, Y12.2
LC_DOUT: U1.12, U4.32
LC_DOUT1: U2.12, U8.32
LC_DOUT2: U9.12, U12.32
LC_DOUT3: U13.12, U16.32
LC_DOUT4: U17.12, U20.32
LC_DOUT5: U21.12, U24.32
LC_DOUT6: U25.12, U28.32
LC_DOUT7: U29.12, U32.32
LC_DOUT8: U33.12, U36.32
LC_DOUT9: U37.12, U40.32
LC_DOUT10: U41.12, U44.32
LC_DOUT11: U45.12, U48.32
LC_SCK: U1.11, U4.1
LC_SCK1: U2.11, U8.1
LC_SCK2: U9.11, U12.1
LC_SCK3: U13.11, U16.1
LC_SCK4: U17.11, U20.1
LC_SCK5: U21.11, U24.1
LC_SCK6: U25.11, U28.1
LC_SCK7: U29.11, U32.1
LC_SCK8: U33.11, U36.1
LC_SCK9: U37.11, U40.1
LC_SCK10: U41.11, U44.1
LC_SCK11: U45.11, U48.1
LV_SCL: Q2.2, R8.1, U3.1
LV_SCL1: Q6.2, R26.1, U5.1
LV_SCL2: Q10.2, R44.1, U10.1
LV_SCL3: Q14.2, R62.1, U14.1
LV_SCL4: Q18.2, R80.1, U18.1
LV_SCL5: Q22.2, R98.1, U22.1
LV_SCL6: Q26.2, R116.1, U26.1
LV_SCL7: Q30.2, R134.1, U30.1
LV_SCL8: Q34.2, R152.1, U34.1
LV_SCL9: Q38.2, R170.1, U38.1
LV_SCL10: Q42.2, R188.1, U42.1
LV_SCL11: Q46.2, R206.1, U46.1
LV_SDA: Q1.2, R9.1, U3.6
LV_SDA1: Q5.2, R27.1, U5.6
LV_SDA2: Q9.2, R45.1, U10.6
LV_SDA3: Q13.2, R63.1, U14.6
LV_SDA4: Q17.2, R81.1, U18.6
LV_SDA5: Q21.2, R99.1, U22.6
LV_SDA6: Q25.2, R117.1, U26.6
LV_SDA7: Q29.2, R135.1, U30.6
LV_SDA8: Q33.2, R153.1, U34.6
LV_SDA9: Q37.2, R171.1, U38.6
LV_SDA10: Q41.2, R189.1, U42.6
LV_SDA11: Q45.2, R207.1, U46.6
unnamed: U4.7, Y2.1
unnamed: D3.A, R5.1
unnamed: U4.8, Y2.3
unnamed: C5.1, JP7.D-, R6.1
unnamed: D1.A, R13.1
unnamed: D2.A, R15.1
unnamed: C2.1, JP7.D+, R1.1
unnamed: R6.2, U6.12
unnamed: R7.1, SJ2.2, U1.15
unnamed: C8.1, R3.2, U1.7
unnamed: C8.2, R4.2, U1.8
unnamed: C14.1, F1.1, JP7.VBUS
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

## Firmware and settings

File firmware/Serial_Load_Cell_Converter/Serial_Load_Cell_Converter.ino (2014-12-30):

/*
 A serial interface for reading and configuring load cells.
 By: Nathan Seidle
 SparkFun Electronics
 Date: November 24th, 2014
 License: This code is public domain but you buy me a beer if you use this and we meet someday (Beerware license).
 
 This example code uses bogde's excellent library: https://github.com/bogde/HX711
 SparkFun spends a lot of time and energy building open source hardware and writing public domain code. 
 Please consider supporting SparkFun by buying a product or kit.
 
 Serial Load Cell Converter is a simple board that allows a user to read and configure all types of load cells.
 It relies on the HX711 load cell amplifier.
 
 How to use: 
 1) Wire your load cell to the board using the 4-pin connection (E+/-, A+/-) or the RJ11 connection.
 2) Attach board to USB and open terminal at 9600bps
 3) Press q to bring up settings menu
 4) Select units LBS/KG
 5) Tare the scale with no weight on the scale
 6) Calibrate the scale: Remove an weight, start calibration routine, place weight on scale, adjust calibration 
 factor until scale reads out the calibration weight.
 7) Press x and test your scale
 
 SLCC ships with an Arduino/Optiboot 115200bps serial bootloader running at 16MHz so you can load new firmware 
 with a simple serial connection.
 
 SLCC runs at 9600bps by default. This is configurable to 1200, 2400, 4800, 9600, 19200, 38400, 57600, and 115200bps. 
 
 Type '?' to get a list of supported commands.
 	
 After power up SLCC will try reading the load cell and output a weight value.
 
 If you get SLCC stuck into an unknown baudrate, there is a safety mechanism built-in. Tie the RX pin 
 to ground and power up SLCC. You should see the LEDs blink back and forth for 2 seconds, then blink 
 in unison. Now power down SLCC and remove the RX/GND jumper. SLCC is now reset to 9600bps.
 
 Type 'set' to enter baud rate configuration menu. Select the baud rate and press enter. You will then 
 see a message 'Going to 9600bps...' or some such message. You will need to power down OpenLog, change 
 your system UART settings to match the new OpenLog baud rate and then power OpenLog back up.
 
 STAT1 LED / D5 - flashes when character is received
 
 TODO:
 Get version numbers into a define - help menu, setup, 
 Change the read range from 100s of lbs to grams or micrograms.
 Make zero range changeable by user


 */

#include "HX711.h"
#include "slcc.h" //Contains EPPROM locations

#include <EEPROM.h>

#define FIRMWARE_VERSION "1.0"

const byte statled1 = 13;  //Flashes with incoming serial traffic

long setting_uart_speed; //This is the baud rate that the system runs at, default is 9600. Can be 1,200 to 1,000,000
byte setting_units; //Lbs or kg?
unsigned int setting_report_rate;
long setting_calibration_factor; //Value used to convert the load cell reading to lbs or kg
long setting_tare_point; //Zero value that is found when scale is tared 
boolean setting_time_stamp; //Prints the number of miliseconds since boot next to weight reading
byte setting_decimal_places; //How many decimals to display
byte setting_average_amount; //How many readings to take before reporting reading

byte setting_zero_window = 1; //

const byte escape_character = 'q'; //This is the ASCII character we look for to break logging

HX711 scale(DAT, CLK); //Setup interface to scale

void setup()
{
  pinMode(statled1, OUTPUT);

  //During testing reset everything
  //for(int x = 0 ; x < 20 ; x++)
  //{
  //  EEPROM.write(x, 0xFF);
  //}

  Serial.begin(9600);
  read_system_settings(); //Load all system settings from EEPROM

  //Setup UART
  Serial.begin(setting_uart_speed);
  Serial.println("Serial Load Cell Converter");
  Serial.println("By SparkFun Electronics");

  check_emergency_reset(); //Look to see if the RX pin is being pulled low

  scale.set_scale(setting_calibration_factor); //Calibrate scale from EEPROM value
  scale.set_offset(setting_tare_point); //Zero out the scale using a previously known zero point

  //Calculate the minimum time between reports
  int minTime = calcMinimumReadTime();
  Serial.print("Minimum time between reports: ");
  Serial.println(minTime);
  
  //Look for a weird case where the report rate time is less than the allowed minimum
  if(setting_report_rate < minTime) setting_report_rate = minTime;
  
  Serial.println("Readings:");
}

long numberOfReadings = 0;
float lastReading = 0;
float totalReadings = 0;

void loop()
{
  long startTime = millis();

  //Print time stamp
  if(setting_time_stamp == true)
  {
    Serial.print(startTime);
    Serial.print(F(","));
  }

  //Take average of readings
  float currentReading = scale.get_units(setting_average_amount);
  
  //Zero out reading if it is too close to zero
  //if(abs(currentReading) < setting_zero_window) currentReading = 0;
  
  Serial.print(currentReading, setting_decimal_places);
  Serial.print(F(","));
  if(setting_units == UNITS_LBS) Serial.print(F("lbs"));
  if(setting_units == UNITS_KG) Serial.print(F("kg"));
//  Serial.println();
  blinkLED(statled1);

  //If we see escape char then drop to setup menu
  if(Serial.available())
  {
    blinkLED(statled1);
    char incoming = Serial.read();
    if(incoming == escape_character) system_setup();
  }

  //Hang out until the end of this report period
  while( (millis() - startTime) < setting_report_rate)
  {
    delay(1);
  }
  
  /*float delta = lastReading - currentReading;
  lastReading = currentReading;
  
  totalReadings += delta;

  numberOfReadings++;
  
  float avgDelta = totalReadings / numberOfReadings;
  
  Serial.print(" Delta: ");
  Serial.print(delta, 3);
  Serial.print(" avgDelta: ");
  Serial.print(avgDelta, 3);*/

  Serial.println();
}


//Configure how SLCC operates
void system_setup(void)
{
  while(1)
  {
    Serial.print(F("\r\nSerial Load Cell Converter version: "));
    Serial.println(F(FIRMWARE_VERSION));
    Serial.println(F("System Configuration"));

    Serial.print(F("1) Tare scale to zero ["));
    Serial.print(setting_tare_point);
    Serial.println(F("]"));

    Serial.print(F("2) Calibrate Scale ["));
    Serial.print(setting_calibration_factor);
    Serial.println(F("]"));

    Serial.print(F("3) Time Stamp ["));
    if(setting_time_stamp == true) Serial.print(F("On"));
    if(setting_time_stamp == false) Serial.print(F("Off"));
    Serial.println(F("]"));

    Serial.print(F("4) Set report rate ["));
    Serial.print(setting_report_rate);
    Serial.println(F("]"));

    Serial.print(F("5) Set baud rate ["));
    Serial.print(setting_uart_speed);
    Serial.println(F(" bps]"));

    Serial.print(F("6) Change units of measure ["));
    if(setting_units == UNITS_KG) Serial.print(F("kg"));
    if(setting_units == UNITS_LBS) Serial.print(F("lbs"));
    Serial.println(F("]"));

    Serial.print(F("7) Decimals ["));
    Serial.print(setting_decimal_places);
    Serial.println(F("]"));

    Serial.print(F("8) Average amount ["));
    Serial.print(setting_average_amount);
    Serial.println(F("]"));

    Serial.println(F("x) Exit"));
    Serial.print(F(">"));

    //Read command
    while(!Serial.available()) ; //Wait for user to type a character
    char command = Serial.read();

    blinkLED(statled1);

    //Execute command
    if(command == '1')
    {
      //This can be used to remove the need to tare the scale.
      //Useful in permanent scale projects.
      Serial.print(F("\n\rTare point: "));

      scale.tare(); //Reset the scale to 0

      setting_tare_point = scale.read_average(10); //Get 10 readings from the HX711 and average them

      Serial.println(setting_tare_point);

      record_system_settings();
    }
    else if(command == '2')
    {
      calibrate_scale();
    }
    else if(command == '3')
    {
      Serial.print(F("\n\rTime stamp set to "));
      if(setting_time_stamp == true)
      {
        Serial.println(F("false"));
        setting_time_stamp = false;
      }
      else
      {
        Serial.println(F("true"));
        setting_time_stamp = true;
      }
      record_system_settings();
    }
    else if(command == '4')
    {
      rate_setup();
    }
    else if(command == '5')
    {
      baud_setup();
    }
    else if(command == '6')
    {
      Serial.print(F("\n\rUnits set to "));
      if(setting_units == UNITS_KG)
      {
        Serial.println(F("lbs"));
        setting_units = UNITS_LBS;
        float newFactor = (float)setting_calibration_factor * 0.453592; //Convert the calibration factor from kg to lbs
        setting_calibration_factor = (long)newFactor;
      }
      else if(setting_units == UNITS_LBS)
      {
        Serial.println(F("kg"));
        setting_units = UNITS_KG;
        float newFactor = (float)setting_calibration_factor * 2.20462; //Convert the calibration factor from lbs to kg
        setting_calibration_factor = (long)newFactor;
      }

      scale.set_scale(setting_calibration_factor); //Assign this new factor to the scale
      record_system_settings();
      
    }
    else if(command == '7')
    {
      decimal_setup();
    }
    else if(command == '8')
    {
      average_reading_setup();
    }
    else if(command == 'x')
    {
      //Do nothing, just exit
      Serial.println(F("Exiting"));
      return;
    }

  }
}

//Configure how many readings to average together
void average_reading_setup(void)
{
  Serial.println(F("Number of readings to average together"));
  Serial.println(F("Press + or a to increase"));
  Serial.println(F("Press - or z to decrease"));
  Serial.println(F("Press x to exit"));

  Serial.print(F("Number of readings: "));
  Serial.println(setting_average_amount);

  while(1)
  {
    if(Serial.available())
    {
      char temp = Serial.read();
      
      if(temp == '+' || temp == 'a')
      {
        if(setting_average_amount < 64) setting_average_amount++;
      }
      else if(temp == '-' || temp == 'z')
      {
        if(setting_average_amount > 1) setting_average_amount--;
      }
      else if(temp == 'x')
        break;

      Serial.print(F("Number of readings: "));
      Serial.println(setting_average_amount);
    }
  }

  //Record this new value to EEPROM
  record_system_settings();
}

//Configure how many decimals to show
void decimal_setup(void)
{
  Serial.println(F("Press + or a to increase number of decimals"));
  Serial.println(F("Press - or z to decrease number of decimals"));
  Serial.println(F("Press x to exit"));

  Serial.print(F("Decimal places: "));
  Serial.println(setting_decimal_places);

  while(1)
  {
    if(Serial.available())
    {
      char temp = Serial.read();
      
      if(temp == '+' || temp == 'a')
      {
        if(setting_decimal_places < 4) setting_decimal_places++;
      }
      else if(temp == '-' || temp == 'z')
      {
        if(setting_decimal_places > 0) setting_decimal_places--;
      }
      else if(temp == 'x')
        break;

      Serial.print(F("Decimal places: "));
      Serial.println(setting_decimal_places);
    }
  }

  //Record this new value to EEPROM
  record_system_settings();
}

//Configure what baud rate to communicate at
void baud_setup(void)
{
  Serial.print(F("\n\rCurrent rate: "));
  Serial.print(setting_uart_speed, DEC);
  Serial.println(F(" bps"));

  Serial.println(F("Enter new baud rate ('x' to exit):"));

  //Print prompt
  Serial.print(F(">"));

  //Read user input
  char newBaud[8]; //Max at 1000000
  read_line(newBaud, sizeof(newBaud));

  //Look for escape character
  if(newBaud[0] == 'x')
  {
    Serial.println(F("Exiting"));
    return;
  }

  long newRate = strtolong(newBaud); //Convert this string to a long

  if(newRate < BAUD_MIN || newRate > BAUD_MAX)
  {
    Serial.println(F("Out of bounds"));
  }
  else
  {
    Serial.print(F("Going to "));
    Serial.print(newRate);
    Serial.println(F("bps"));

    //Record this new baud rate
    setting_uart_speed = newRate;
    record_system_settings();

    //Go to this speed
    Serial.end();
    Serial.begin(setting_uart_speed);
  }
}

//Determine how much time we need between measurements
//Takes into account current baud rate
int calcMinimumReadTime(void)
{
  //The first few reads take too little time
  scale.get_units();
  scale.get_units();

  //Now do an average
  long startTime = millis();
  for(byte x = 0 ; x < 8 ; x++)
    scale.get_units(); //Do a dummy read and time it
  int averageReadTime = (millis() - startTime) / 8;
  
  averageReadTime *= setting_average_amount; //Increase this time by the number of system reads we want to do

  //Assume we will need to print a minimum of 7 characters at this baud rate per loop
  //1 / 9600 = 1ms * 10bits per byte = 9.6ms per byte
  float characterTime = 10000 / (float)setting_uart_speed;

  //Calculate number of characters per report
  //"51588595,178.899,lbs"
  int characters = strlen("123.,"); //Basic case

  characters += setting_decimal_places; //For example this would pickup 3 of '17.123'

  if(setting_units == UNITS_LBS) characters += strlen("lbs");
  if(setting_units == UNITS_KG) characters += strlen("kg");

  if(setting_time_stamp == true) characters += strlen("51588595,"); //14.33 hours

  //Serial.print("characterTime: ");
  //Serial.println(ceil((float)characters * characterTime));
  
  return(averageReadTime + ceil((float)characters * characterTime)); 
}

//Gives user the ability to set a known weight on the scale and calculate a calibration factor
void calibrate_scale(void)
{
  Serial.println(F("Scale calibration"));
  Serial.println(F("Remove all weight from scale"));
  Serial.println(F("After readings begin, place known weight on scale"));
  Serial.println(F("Press + or a to increase calibration factor"));
  Serial.println(F("Press - or z to decrease calibration factor"));
  Serial.println(F("Press x to exit"));

  delay(3000); //Delay so user can read instructions

  long lastChange = millis();
  int changeRate = 1;
  int holdDownCounter = 0;

  while(1)
  {
    scale.set_scale(setting_calibration_factor); //Adjust to this calibration factor

    Serial.print(F("Reading: ["));
    Serial.print(scale.get_units(setting_average_amount), 4); //Show 4 decimals during calibration
    //Serial.print(scale.get_units(setting_average_amount), setting_decimal_places);
    Serial.print(F(" "));
    if(setting_units == UNITS_LBS) Serial.print(F("lbs"));
    if(setting_units == UNITS_KG) Serial.print(F("kg"));
    Serial.print(F("]   Calibration Factor: "));
    Serial.print(setting_calibration_factor);
    Serial.println();

    if(Serial.available())
    {
      //blinkLED(statled1); //Blink serial indicator

      //Check to see if user is holding down the button
      long delta = millis() - lastChange;
      lastChange = millis();
      
      if(delta > 100) //Slow, just 1 and reset holdDown counter
      {
        changeRate = 1;
        holdDownCounter = 0;
      }
      else //Medium 10 and increment counter
      {
        changeRate = 10;
        holdDownCounter++;
        if(holdDownCounter > 60)
        {
          holdDownCounter = 100; //Don't let this get too big
          changeRate = 100; //Change faster
        }
        else if(holdDownCounter > 25)
        {
          changeRate = 25; //Change faster
        }
      }

      while(Serial.available())
      {
        char temp = Serial.read();
  
        if(temp == '+' || temp == 'a')
          setting_calibration_factor += changeRate;
        else if(temp == '-' || temp == 'z')
          setting_calibration_factor -= changeRate;
        else if(temp == 'x')
        {
          //Record this new value to EEPROM
          record_system_settings();
          return;
        }
      }
    }
  }

}

//Allow user to input the time between readings
void rate_setup(void)
{
  //Calculate the minimum time between reports
  int minTime = calcMinimumReadTime();
  
  Serial.println(F("Press + or a to increase time between reports"));
  Serial.println(F("Press - or z to decrease time between reports"));
  Serial.println(F("Press x to exit"));

  Serial.print(F("Minimum: "));
  Serial.print(minTime);
  Serial.println("ms");
  
  if(setting_report_rate < minTime) setting_report_rate = minTime;

  Serial.print(F("Time: "));
  Serial.print(setting_report_rate);
  Serial.println("ms");

  long lastChange = millis();
  int changeRate = 1;
  int holdDownCounter = 0;
  
  while(1)
  {
    if(Serial.available())
    {
      char temp = Serial.read();
      
      //Check to see if user is holding down the button
      long delta = millis() - lastChange;
      lastChange = millis();
      
      if(delta > 100) //Slow, just change one at a time and reset holdDown counter
      {
        changeRate = 1;
        holdDownCounter = 0;
      }
      else //You're holding the button down, change 10, 25, or500300 medium 10 and increment counter
      {
        changeRate = 10;
        holdDownCounter++;
        if(holdDownCounter > 500)
        {
          holdDownCounter = 500; //Don't let this get too big
          changeRate = 500; //Change faster
        }
        else if(holdDownCounter > 25)
        {
          changeRate = 25; //Change faster
        }
      }

      if(temp == '+' || temp == 'a')
        setting_report_rate += changeRate;
      else if(temp == '-' || temp == 'z')
        setting_report_rate -= changeRate;
      else if(temp == 'x')
        break;

      if(setting_report_rate < minTime) setting_report_rate = minTime;
      if(setting_report_rate > 50000) setting_report_rate = 50000; //Max of 50 seconds

      Serial.print(F("Time: "));
      Serial.print(setting_report_rate);
      Serial.println("ms");
    }
  }

  //Record this new value to EEPROM
  record_system_settings();
}

//Given a pin number with an LED on it, blink it briefly
void blinkLED(byte LED)
{
  digitalWrite(LED, HIGH);
  delay(25);
  digitalWrite(LED, LOW);
  delay(25);
}

//Check to see if we need an emergency UART reset
//Scan the RX pin for 2 seconds
//If it's low the entire time, then return 1
void check_emergency_reset(void)
{
  pinMode(0, INPUT); //Turn the RX pin into an input
  digitalWrite(0, HIGH); //Push a 1 onto RX pin to enable internal pull-up

  //Quick pin check
  if(digitalRead(0) == HIGH) return;

  Serial.println("Reset!");

  //Wait 2 seconds, blinking LED while we wait
  pinMode(statled1, OUTPUT);
  digitalWrite(statled1, LOW); //Set the STAT1 LED

  for(byte i = 0 ; i < 80 ; i++)
  {
    delay(25);

    if(digitalRead(statled1) == LOW) digitalWrite(statled1, HIGH);
    else digitalWrite(statled1, LOW);

    if(digitalRead(0) == HIGH) return; //Check to see if RX is not low anymore
  }		

  //If we make it here, then RX pin stayed low the whole time
  set_default_settings(); //Reset baud, escape characters, escape number, system mode

  pinMode(statled1, OUTPUT);
  digitalWrite(statled1, HIGH);

  //Now sit in forever loop indicating system is now at 9600bps
  while(1)
  {
    delay(500);

    //Blink stat LEDs
    if(digitalRead(statled1) == LOW) digitalWrite(statled1, HIGH);
    else digitalWrite(statled1, LOW);
  }
}

//Resets all the system settings to safe values
void set_default_settings(void)
{
  //Reset UART to 9600bps
  setting_uart_speed = 9600;

  //Reset to pounds as our unit of measure
  setting_units = UNITS_LBS;

  //Reset report rate to 5Hz
  setting_report_rate = 200;

  //Reset calibration factor
  setting_calibration_factor = 1000;

  //Reset tare point
  setting_tare_point = 0;

  //Reset time stamp
  setting_time_stamp = true;
  
  //Reset decimals
  setting_decimal_places = 2;
  
  //Reset average amount
  setting_average_amount = 4;

  //Commit these new settings to memory  
  record_system_settings();
}

//Record the current system settings to EEPROM
void record_system_settings(void)
{
  writeBytes(LOCATION_BAUD_MSB, setting_uart_speed, sizeof(setting_uart_speed));

  EEPROM.write(LOCATION_MASS_UNITS, setting_units);

  writeBytes(LOCATION_REPORT_RATE_MSB, setting_report_rate, sizeof(setting_report_rate));

  writeBytes(LOCATION_CALIBRATION_FACTOR_MSB, setting_calibration_factor, sizeof(setting_calibration_factor));

  writeBytes(LOCATION_TARE_POINT_MSB, setting_tare_point, sizeof(setting_tare_point));

  EEPROM.write(LOCATION_TIME_STAMP, setting_time_stamp);

  EEPROM.write(LOCATION_DECIMAL_PLACES, setting_decimal_places);

  EEPROM.write(LOCATION_AVERAGE_AMOUNT, setting_average_amount);
}
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

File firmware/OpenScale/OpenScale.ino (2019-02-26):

/*
  OpenScale: A serial interface for reading and configuring load cells.
  By: Nathan Seidle
  SparkFun Electronics
  Date: November 24th, 2014
  License: This code is public domain but you buy me a beer if you use this and we meet someday (Beerware license).

  This example code uses bogde's excellent library: https://github.com/bogde/HX711
  SparkFun spends a lot of time and energy building open source hardware and writing public domain code.
  Please consider supporting SparkFun by buying a product or kit.

  OpenScale is a simple board that allows a user to read and configure all types of load cells.
  It relies on the HX711 load cell amplifier.

  How to use:
  1) Wire your load cell to the board using the 4-pin connection (E+/-, A+/-) or the RJ45 connection.
  2) Attach board to USB and open terminal at 9600bps
  3) Press x to bring up settings menu
  4) Select units LBS/KG
  5) Tare the scale with no weight on the scale
  6) Calibrate the scale: Remove any weight, start calibration routine, place weight on scale, type
  in the weight placed on the scale.
  7) Press x and test your scale

  OpenScale ships with an Arduino/Optiboot 115200bps serial bootloader running at 16MHz so you can load new firmware
  with a simple serial connection. Select 'Arduino Uno' under the boards menu to reprogram the board.

  OpenScale runs at 9600bps by default. This is configurable to 1200, 2400, 4800, 9600, 19200, 38400, 57600, and 115200bps.

  After power up OpenScale will try reading the load cell and output a weight value.

  If you get OpenScale stuck into an unknown baudrate, there is a safety mechanism built-in. Tie the RX pin
  to ground and power up OpenScale. You should see the status LED blink at 1Hz for 2 seconds.
  Now power down OpenScale and remove the RX/GND jumper. OpenScale is now reset to 9600bps.

  To change the baud rate type 'x' to bring up configuration menu. Select the baud rate sub menu and enter
  the baud rate of your choice. You will then see a message for example 'Going to 9600bps...'.
  You will need to power down OpenScale, change your system UART settings to match the new OpenScale
  baud rate and then power OpenScale back up.

  STAT LED / D13 - toggles after each report

  If you're using this firmware with the HX711 breakout and an Uno here are the pins to hook up:
  Arduino pin 2 -> HX711 CLK
  3 -> DAT
  5V -> VCC
  GND -> GND

  Firmware versions:
  v1.0 - Original release
  v1.1 - Added trigger character
  v1.2 - 
  * Cleaned up white space and split to tabs for easier function finding
  * Changed the input method of many menu settings from the tedious +/- method
  to text enter. Now you can calibrate your system by typing in '0.5762' and OpenScale
  will figure out all the calibration factors.
  * Fixed a bug with the EEPROM defaulting to the wrong values
*/

#include "HX711.h" //Original Repository Created by Bodge https://github.com/bogde/HX711
#include "openscale.h" //Contains EPPROM locations for settings
#include <Wire.h> //Needed to talk to on board TMP102 temp sensor
#include <EEPROM.h> //Needed to record user settings
#include <OneWire.h> //Needed to read DS18B20 temp sensors

#include <avr/sleep.h> //Needed for sleep_mode
#include <avr/power.h> //Needed for powering down perihperals such as the ADC/TWI and Timers

#define FIRMWARE_VERSION "1.2"

//Global variables
//-=-=-=-=-=-=-=-=-=-=-=-=-=-=-=-=-=-=-=-=-=-=-=-=-=-=-=-=-=-=-=-=-=-=-
long setting_uart_speed; //This is the baud rate that the system runs at, default is 9600. Can be 1,200 to 1,000,000
byte setting_units; //Lbs or kg?
unsigned int setting_report_rate;
long setting_calibration_factor; //Value used to convert the load cell reading to lbs or kg
long setting_tare_point; //Zero value that is found when scale is tared
boolean setting_timestamp_enable; //Prints the number of miliseconds since boot next to weight reading
byte setting_decimal_places; //How many decimals to display
byte setting_average_amount; //How many readings to take before reporting reading
byte setting_local_temp_enable; //Prints the local temperature in C
byte setting_remote_temp_enable; //Prints the remote temperature in C
byte setting_status_enable; //Turns on/off the blinking status LED
byte setting_serial_trigger_enable; //Takes reading when serial character is received
byte setting_raw_reading_enable; //Prints the raw, 24bit, long from the HX711, ex: 8355808
byte setting_trigger_character; //The character that will cause OpenScale to report a reading
boolean setupMode = false; //This is set to true if user presses x

const byte escape_character = 'x'; //This is the ASCII character we look for to break reporting
const int minimum_powercycle_time = 500; //Anything less than 500 can cause reading problems
//-=-=-=-=-=-=-=-=-=-=-=-=-=-=-=-=-=-=-=-=-=-=-=-=-=-=-=-=-=-=-=-=-=-=-

const byte statusLED = 13;  //Flashes with each reading

HX711 scale; //Setup interface to scale

OneWire remoteSensor(4);  //Setup reading one wire temp sensor on pin 4 (a 4.7K resistor is necessary)
byte remoteSensorAddress[8];
boolean remoteSensorAttached = false;

void setup()
{
  pinMode(statusLED, OUTPUT);

  scale.begin(DAT, CLK);

  //Power down various bits of hardware to lower power usage
  set_sleep_mode(SLEEP_MODE_IDLE);
  sleep_enable();

  //Shut off Timer2, Timer1, ADC
  ADCSRA &= ~(1 << ADEN); //Disable ADC
  ACSR = (1 << ACD); //Disable the analog comparator
  DIDR0 = 0x3F; //Disable digital input buffers on all ADC0-ADC5 pins
  DIDR1 = (1 << AIN1D) | (1 << AIN0D); //Disable digital input buffer on AIN1/0

  power_timer1_disable();
  power_timer2_disable();
  power_adc_disable();
  power_spi_disable();

  //During testing reset everything
  //for(int x = 0 ; x < 30 ; x++)
  //  EEPROM.write(x, 0xFF);

  Wire.begin();

  readSystemSettings(); //Load all system settings from EEPROM

  //Setup UART
  Serial.begin(setting_uart_speed);
  displaySystemHeader(); //Product title and firmware version

  checkEmergencyReset(); //Look to see if the RX pin is being pulled low

  scale.set_scale(setting_calibration_factor);
  scale.set_offset(setting_tare_point);

  //Calculate the minimum time between reports
  int minTime = calcMinimumReadTime();
  Serial.print(F("Minimum time between reports: "));
  Serial.println(minTime);

  //Look for a special case where the report rate time is less than the allowed minimum
  if (setting_report_rate < minTime) setting_report_rate = minTime;

  Serial.print(F("Press "));
  Serial.print((char)escape_character);
  Serial.println(F(" to bring up settings"));

  Serial.println(F("Readings:"));

  powerUpScale(); //Be sure the scale is powered up
}
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

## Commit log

2014-12-20 Initial commit
    Firmware is mostly done. Hardware is mostly done.
    [Serial Load Cell converter.brd, Serial Load Cell converter.sch]
2014-12-23 Small fixes to pass initial QC checklist
    [Serial Load Cell converter.brd, Serial Load Cell converter.sch]
2014-12-23 Fixing file locations.
    [Serial Load Cell converter.brd, Serial Load Cell converter.sch]
2014-12-23 Added external serial connection.
    Can be used to emergency reset the serial interface back to 9600bps.
    [Serial Load Cell converter.brd, Serial Load Cell converter.sch]
2014-12-30 First round of fixes from PLewis review
    Fixed J1/J3 labels on schematic. Fixed LED colors to match standards.
    Added test point for VCC. Improved layout around TMP102. Added measures.
    [Serial Load Cell converter.brd, Serial Load Cell converter.sch]
2014-12-30 Fixing issue #1
    [Serial Load Cell converter.brd, Serial Load Cell converter.sch]
2015-01-15 Update file names. Remove stat LED blink delay.
    [Serial Load Cell converter.brd, Serial Load Cell converter.sch]
2015-02-05 Lots of changes. v02 ready for proto.
    Changed to RJ45, FTDI connection, MOSFETs to temp sensor, silk, shutdown
    from temp sensor to ATmega.
    [OpenScale.brd, OpenScale.sch]
2015-02-05 Silk fix. Dim fix. Reroute traces to TMP102.
    [OpenScale.brd]
2015-02-06 Bumped RJ45 to fix issue #3
    [OpenScale.brd]
2015-03-23 Adding support for temperature readings.
    [OpenScale.brd, OpenScale.sch]
2015-04-09 Remove v-reg add PNP for internal v-reg.
    Added 4.7k pull up for One Wire external temp.
    [OpenScale.brd, OpenScale.sch]
2015-04-09 Fixed issue 4 - DRC errors and schematic markings.
    [OpenScale.brd, OpenScale.sch]
2015-04-09 Crazy re-design to use screw terminals.
    Rather than RJ45 I have moved to screw terminals. This should make it
    easy on end customers who don't have a solder iron to get up and running
    immediately.
    [OpenScale.brd, OpenScale.sch]
2015-04-13 New version with screw terminals. Ready for review.
    [OpenScale.brd, OpenScale.sch]
2015-04-13 Silkscreen fix.
    [OpenScale.brd]
2015-10-12 Fix screw terminal spacing. Small firmware changes.
    Footprint error on the screw terminals that prevented them from being
    linked together (spaced too far apart). Should be fixed now but needs
    double checking.
    [OpenScale.brd, OpenScale.sch]
2016-03-07 Adding Working Copies of New Rev
    [openScale_v04.brd, openScale_v04.sch]
2016-03-07 Delete openScale_v04.brd
    Should not be in master
    [openScale_v04.brd]
2016-03-15 Updated Board files
    [openScale_v04.brd, openScale_v04.sch]
2016-03-15 Updated Board and Schematic
    [openScale_v04.brd, openScale_v04.sch]
2016-03-15 Updated Board and Schematic after reviewing QC checklist
    [openScale_v04.brd, openScale_v04.sch]
2016-03-15 Updated Board file
    [openScale_v04.sch]
2016-03-29 Updated Board and Schematic files per QC checklist
    [openScale_v04.brd, openScale_v04.sch]
2016-03-29 Updated yellow LED
    [openScale_v04.brd, openScale_v04.sch]
2016-05-02 Updated Board and Schemtic
    [openScale_v04.brd, openScale_v04.sch]
2016-05-03 Updated silk on brd file
    [openScale_v04.brd]
2016-05-06 Adding power savings to main firmware
    If unit is in trigger mode it will now shut down to about 4mA in sleep
    mode. It wakes up when a character is received. Removing extra testing
    sketches.
2016-05-09 Updated BRD and SCH file per Engineering Design Review
    [openScale_v04.brd, openScale_v04.sch]
2016-05-11 Updated Brd and Sch files per QC review.
    [openScale_v04.brd, openScale_v04.sch]
2016-05-11 Changed silk: Centered bottom layer text on FTDI headers
    [openScale_v04.brd]
2016-06-01 created panel v10
    [SparkFun_OpenScale_Panel_v10.brd]
2016-07-12 Updated OpenScale with Power Reduction and Trigger Character
2016-07-15 removed tmp102 silk from panel v10
    [SparkFun_OpenScale_Panel_v10.brd]
2016-12-01 Value Additions to .brd and .sch for 3D Model
    [OpenScale.brd, OpenScale.sch]
2017-01-26 Updated firmware -- Calibrated Tare will now save in EEPROM after power cycle
2017-01-26 Updated firmware -- Calibrated tare point will be saved to EEPROM after power cycle
2017-01-26 Updated Firmware -- Calibrated Tare Point will be saved in EEPROM after power cycle
2017-02-08 set tare point and calibration fac after loading vals on startup
2018-11-06 New calibration works
2018-11-06 Broke the spagetti code into individual tabs
    [Menus.ino, OpenScale.ino, System.ino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]
2018-11-06 Temp removed scale power cycling. Fixed double menu issue.
    [OpenScale.ino, System.ino, openscale.h]
2018-11-06 Default EEPROM settings now load correctly
    The boolean variables were coming in as not > 1, so they were defaulting to 255. By casting these settings as bytes, they test correctly. Might have been a compiler change in Arduino? Or it never properly went to defaults.
    [Menus.ino, OpenScale.ino]
2018-11-06 Calibration now echos user's input
2018-11-06 Removed scale power cycling. Maintained ATmega sleep.
    Power cycle the HX711 was causing a reading to be dropped every once and awhile causing the calibration routine and general reading to fail. Works now, but at the expense of ~1.5mA additional.
    [OpenScale.ino]
2018-11-06 Fixed the set_default_settings settings.
    [Menus.ino, System.ino]
2019-05-15 Update SparkFun_openScale.sch
    Updating AVDD equation to be correct
    [SparkFun_openScale.sch]

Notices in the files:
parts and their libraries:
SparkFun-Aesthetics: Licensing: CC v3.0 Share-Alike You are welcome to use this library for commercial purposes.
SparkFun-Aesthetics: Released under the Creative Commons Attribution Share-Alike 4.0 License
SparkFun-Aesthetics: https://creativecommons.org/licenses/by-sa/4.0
